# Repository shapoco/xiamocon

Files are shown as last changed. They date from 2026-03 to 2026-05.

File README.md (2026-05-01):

# [WIP] Xiamocon

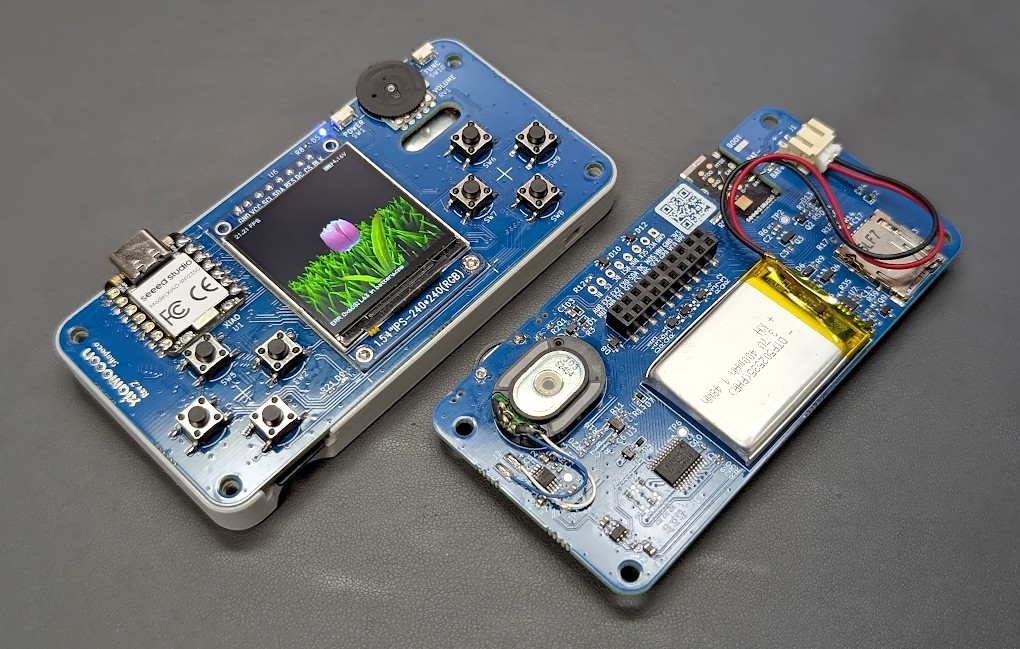
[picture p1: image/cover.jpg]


Game-console-style motherboard for XIAO RP2350/ESP32S3

> [!CAUTION]
> Everything is currently under development. Breaking changes may occur frequently without notice.

## Hardware Architecture

[Schematic](https://kicanvas.org/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)

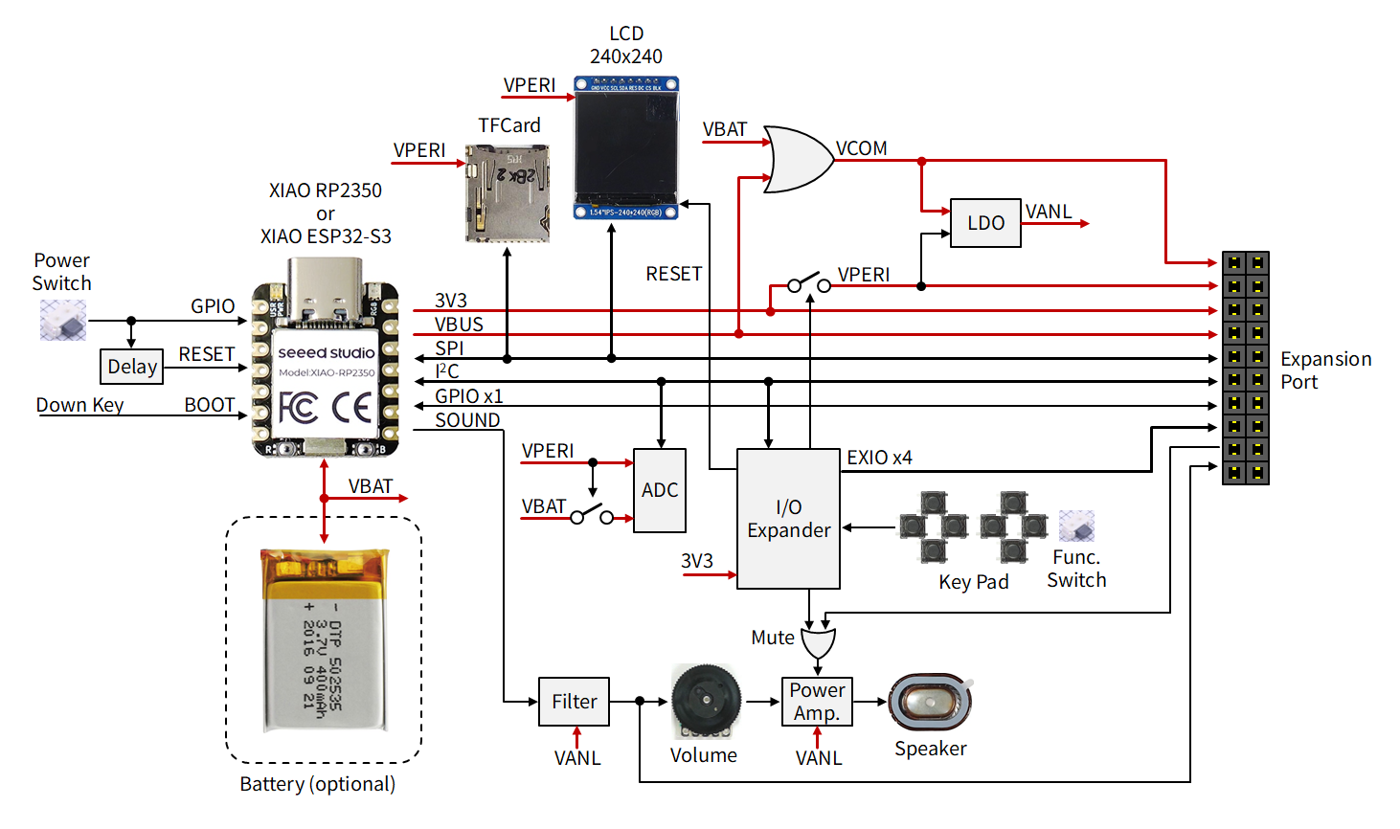
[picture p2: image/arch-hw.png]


## Development Environment Setup (Ubuntu24.04/macOS)

### 1. Install Build Tools

#### Install uv

See [Installing uv](https://docs.astral.sh/uv/getting-started/installation/).

#### Install other required packages

- Ubuntu24.04 (WSL2):

    ```sh
    sudo apt update
    sudo apt -y install curl git
    sudo apt -y install build-essential cmake gcc-arm-none-eabi
    ```

- macOS:

    First, install Command Line Developer Tools, [Homebrew](https://brew.sh/), and [CMake](https://cmake.org/download/), then run the following command:

    ```sh
    sudo "/Applications/CMake.app/Contents/bin/cmake-gui" --install
    brew install --cask gcc-arm-embedded
    ```

### 2. Install the Xiamocon SDK

```sh
curl -LsSf https://github.com/shapoco/xiamocon/raw/refs/heads/main/install.sh | bash
```

Python virtual enviroment, [Pico-SDK](https://github.com/raspberrypi/pico-sdk),
[Pico-Extras](https://github.com/raspberrypi/pico-extras), [PlatformIO](https://platformio.org/),
and this repository will be automatically installed in `${HOME}/.xmc/` directory.

### 3. Configure Environment Variables

To avoid setting the repository path every time, add the following line to your shell configuration file (e.g., `~/.bashrc`, `~/.zshrc`).

```sh
export XMC_REPO_PATH=${HOME}/.xmc/xiamocon
```

## Build and Run the Hello World Sample (Ubuntu24.04/macOS)

### For XIAO RP2350

1. Connect Xiamocon to your PC via USB and enter mass storage mode.
    1. Press and hold the Down button on Xiamocon.
    2. Press and hold the power button for 3 seconds to reset (it will be mounted as a mass storage device).
    3. Release the Down button.
2. Initialize the environment and move to the sample app directory.

    ```sh
    source ${HOME}/.xmc/setup.shrc
    cd ${XMC_REPO_PATH}
    cd cpp/example/hello_world
    ```

3. Build and flash the firmware.
    - On WSL2, you can specify the drive letter with the `-d` option to build and flash in one step (if the drive letter is E). You may be prompted for an administrator password.

        ```sh
        xmc run -p rp2350_pico_sdk -d E
        ```

    - On non-WSL2 environments, run `xmc build` instead of `xmc run`, then manually copy the generated UF2 file to the drive.

        ```sh
        xmc build -p rp2350_pico_sdk
        ```

### For XIAO ESP32S3

1. Connect Xiamocon to your PC via USB and check the serial port.
    - On WSL2, use [WSL USB Manager](https://github.com/nickbeth/wsl-usb-manager) or similar tools to attach Xiamocon's USB device to WSL2.
2. Initialize the environment and move to the sample app directory.

    ```sh
    source ${HOME}/.xmc/setup.shrc
    cd ${XMC_REPO_PATH}
    cd cpp/example/hello_world
    ```

3. Build and flash while specifying the serial port with the `-s` option.

    ```sh
    xmc run -p esp32s3_pio_arduino -s /dev/ttyACM0
    ```

    If you want to use PlatformIO's default serial port, you can omit the `-s` option.

>[!NOTE]
> - You can omit the `-p` option by setting the platform in the `XMC_DEFAULT_PLATFORM` environment variable.
> - You can omit the `-d` option by setting the drive letter in the `XMC_DEFAULT_DRIVE` environment variable.
> - You can omit the `-s` option by setting the serial port in the `XMC_DEFAULT_SERIAL` environment variable.

>[!NOTE]
> On ESP32S3, you can also build and flash using the PlatformIO extension in VSCode.

## Create a Project (Ubuntu24.04/macOS)

```sh
source ${HOME}/.xmc/setup.shrc
mkdir -p my_project
cd my_project
xmc init
cp -r ${XMC_REPO_PATH}/cpp/example/hello_world/src .
```

## Detailed Documentation

See the [Reference Manual](https://shapoco.github.io/xiamocon/ref/).

## Photos

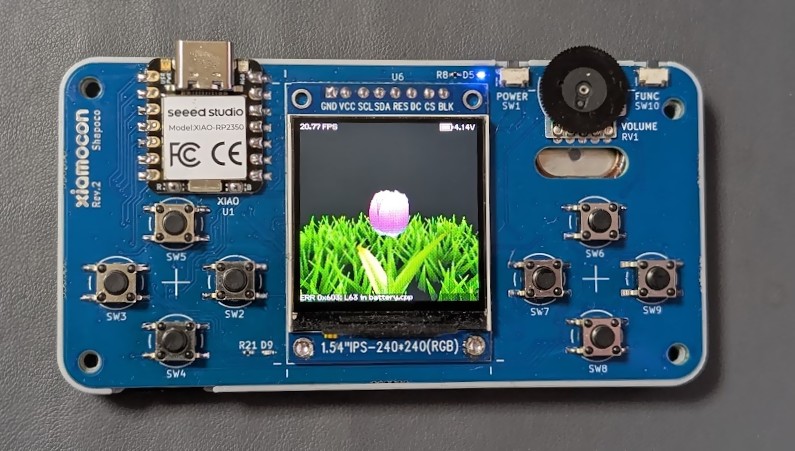
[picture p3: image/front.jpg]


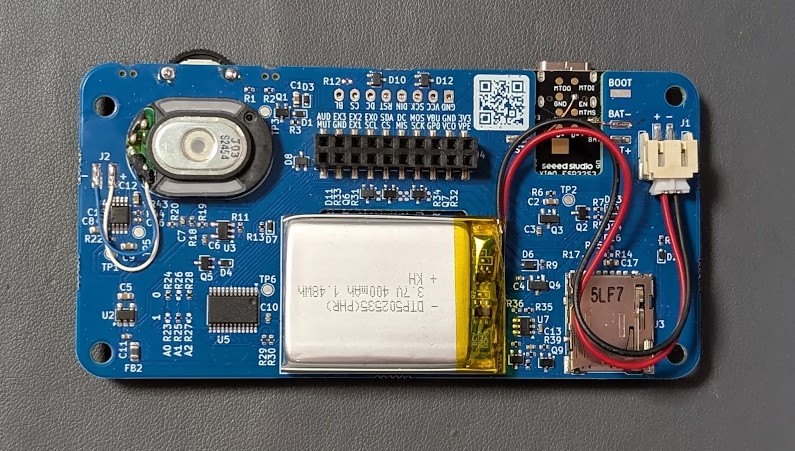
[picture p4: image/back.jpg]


## Videos

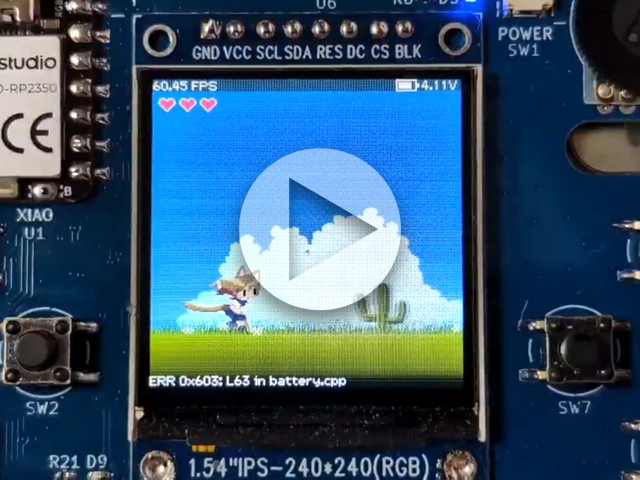
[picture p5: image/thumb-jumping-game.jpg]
(https://x.com/shapoco/status/2041168789505794345)


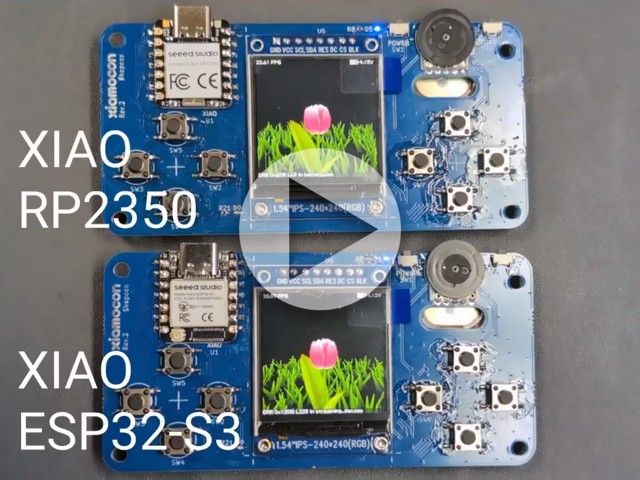
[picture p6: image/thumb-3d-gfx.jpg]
(https://x.com/shapoco/status/2038788120653824424)


## License

T.B.D.

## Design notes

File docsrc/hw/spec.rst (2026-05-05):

ハードウェア仕様
################################################################################

基本仕様
================================================================================

.. csv-table::
   :header: "項目", "値"

   "基板外形", "100x50mm"
   "MCU ボード", "Seeed Studio XIAO RP2350 または XIAO ESP32S3"
   "ディスプレイ", "1.54インチ 240x240px IPS 液晶 (ST7789)"
   "スピーカー", "ダイナミックスピーカー"
   "キーパッド", "タクトスイッチまたはゴム接点"
   "バッテリー(別売)", "DTP502535 (3.7V 400mAh)"
   "メモリーカード(別売)", "SPIモード専用"
   "拡張ポート", "20pin ピンソケット (I2C、SPI、GPIOx5、オーディオ)"
   "消費電力 (RP2350)", "約 400mW (100mA @ 4V)"
   "消費電力 (ESP32S3)", "約 500mW (120mA @ 4V)"
   "待機電流 (RP2350)", "約 80μA"
   "待機電流 (ESP32S3)", "約 20μA"

回路図
================================================================================

`xiamocon.kicad_sch <https://kicanvas.org/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>`__

電源
================================================================================

VBUS
--------------------------------------------------------------------------------

XIAO から供給される 5V の電源です。
USB ケーブルが接続されていれば XIAO の MCU の状態に関わらず常に供給されます。

VBAT
--------------------------------------------------------------------------------

バッテリーから供給される電源です。
バッテリーが接続されていれば XIAO の MCU の状態に関わらず常に供給されます。

3V3
--------------------------------------------------------------------------------

XIAO に内蔵された DC/DC コンバータによって生成される 3.3V の電源です。
USB ケーブルまたはバッテリーが接続されていれば、XIAO の MCU の状態に関わらず常に供給されます。

VPERI
--------------------------------------------------------------------------------

VPERI はペリフェラルに供給される 3.3V の電源です。
次の条件が両方満たされると供給されます。

- IO エキスパンダの PERI_EN_N が Low であること
- ディスプレイの CS と DC が少なくとも短時間 High であること

ディスプレイの CS と DC が長時間 Low またはハイインピーダンスになると、
PERI_EN_N が Low であっても VPERI の供給は停止します。
これにより XIAO のブートローダーが起動している間はペリフェラルの電源供給が停止します。

VCOM
--------------------------------------------------------------------------------

VCOM は VBUS (5V) と VBAT (バッテリー電圧) のうち高い方が供給されます。
VPERI とは無関係に供給されます。

VANL
--------------------------------------------------------------------------------

VANL はオーディオ回路の供給される 3.3V の電源で、VCOM からシリーズレギュレータによって生成されます。
シリーズレギュレータのイネーブルは VPERI と連動します。

ペリフェラル
================================================================================

電源スイッチ
--------------------------------------------------------------------------------

.. csv-table::
   :header: "信号名", "ピン (RP2350)", "ピン (ESP32S3)"

   "POWER", GPIO 27, GPIO 2

電源スイッチは遅延回路を介して XIAO のリセット端子にも接続されており、
長押しすることによってリセットすることができます。

ディスプレイ
--------------------------------------------------------------------------------

.. csv-table::
   :header: "信号名", "ピン (RP2350)", "ピン (ESP32S3)"

   "SCK", GPIO 2, GPIO 7
   "MOSI", GPIO 3, GPIO 9
   "DC", GPIO 28, GPIO 3
   "CS", GPIO 5, GPIO 4

リセット端子は IO エキスパンダの PORTA の 5 番に接続されています。

ディスプレイの電源は VPERI によって供給されます。

メモリーカード
--------------------------------------------------------------------------------

.. csv-table::
   :header: "信号名", "ピン (RP2350)", "ピン (ESP32S3)"

   "SCK", GPIO 2, GPIO 7
   "MOSI", GPIO 3, GPIO 9
   "MISO", GPIO 4, GPIO 8
   "CS", GPIO 0, GPIO 43

CS ピンを Low にドライブするとアクセスランプが点灯します。

メモリーカードの電源は VPERI によって供給されます。

オーディオ
--------------------------------------------------------------------------------

.. csv-table::
   :header: "信号名", "ピン (RP2350)", "ピン (ESP32S3)"

   "AUDIO_OUT", GPIO 1, GPIO 44

オーディオ出力はバッファ、ローパスフィルタ、ボリュームを介してパワーアンプに接続されます。
XIAO からの出力は PDM または PWM を想定しています。
パワーアンプのミュート端子は IO エキスパンダのポート A の 6 番に接続されています。

GPIO
--------------------------------------------------------------------------------

.. csv-table::
   :header: "信号名", "ピン (RP2350)", "ピン (ESP32S3)"

   "GPIO_0", GPIO 26, GPIO 1

GPIO 端子は拡張ポートに接続されています。

IO エキスパンダ
--------------------------------------------------------------------------------

デバイス: PCA9555

.. csv-table::
   :header: "型番", "デバイスアドレス"

   "PCA9555", "0x22"

.. csv-table::
   :header: "信号名", "ピン (RP2350)", "ピン (ESP32S3)"

   "SDA", GPIO 6, GPIO 5
   "SCL", GPIO 7, GPIO 6

.. csv-table::
   :header: "信号名", "接続先", "極性"

   "PORTA-0", "拡張ポート IOEX0", "ユーザー定義"
   "PORTA-1", "拡張ポート IOEX1", "ユーザー定義"
   "PORTA-2", "拡張ポート IOEX2", "ユーザー定義"
   "PORTA-3", "拡張ポート IOEX3", "ユーザー定義"
   "PORTA-4", "ペリフェラルイネーブル (PERI_EN_N)", "Low アクティブ"
   "PORTA-5", "ディスプレイリセット", "Low アクティブ"
   "PORTA-6", "オーディオミュート", "Low アクティブ"
   "PORTA-7", "ファンクションスイッチ", "Low アクティブ"
   "PORTB-0", "A ボタン", "Low アクティブ"
   "PORTB-1", "B ボタン", "Low アクティブ"
   "PORTB-2", "Y ボタン", "Low アクティブ"
   "PORTB-3", "X ボタン", "Low アクティブ"
   "PORTB-4", "↑ボタン", "Low アクティブ"
   "PORTB-5", "↓ボタン", "Low アクティブ"
   "PORTB-6", "←ボタン", "Low アクティブ"
   "PORTB-7", "→ボタン", "Low アクティブ"

バッテリー監視用 ADC
--------------------------------------------------------------------------------

.. csv-table::
   :header: "型番", "デバイスアドレス"

   "ADC101C027", "0x52"

.. csv-table::
   :header: "信号名", "ピン (RP2350)", "ピン (ESP32S3)"

   "SDA", GPIO 6, GPIO 5
   "SCL", GPIO 7, GPIO 6

ADC の電源は VPERI によって供給されます。

拡張ポート
=================================================================================

拡張ポートは基板の背面にあります。XIAO に近い側が 1 番ピンです。

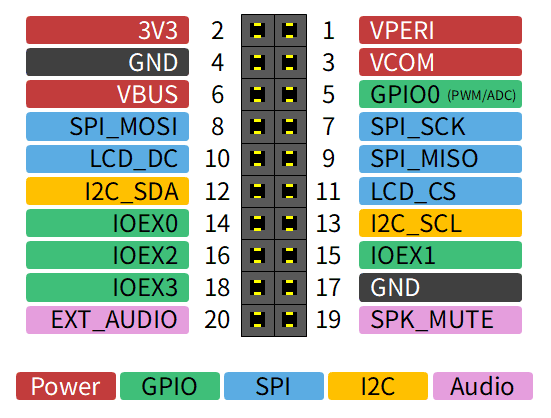
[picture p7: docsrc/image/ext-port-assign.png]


EXT_AUDIO はオーディオ回路から分岐した信号で、XIAO からのオーディオ出力を外部へ出力したり、
逆に外部からのオーディオ信号を入力して XIAO の出力とミックスしてスピーカーから出力できます。

SPK_MUTE はパワーアンプのミュート端子に接続されており、
High にドライブすることでXiamocon 本体のスピーカーをミュートできます。

GPIO0 と IOEX0-3 の用途はアプリ側で自由に定義できます。

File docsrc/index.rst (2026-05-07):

.. xiamocon documentation master file, created by
   sphinx-quickstart on Mon Apr 27 18:01:40 2026.
   You can adapt this file completely to your liking, but it should at least
   contain the root `toctree` directive.

Xiamocon Reference Manual
################################################################################

.. toctree::
   :maxdepth: 2
   :caption: Contents:

   hw/spec.rst
   hw/enclosure.rst
   sdk/app.rst
   sdk/gfx2d.rst
   sdk/gfx3d.rst
   sdk/audio.rst
   sdk/gpio.rst
   sdk/i2c.rst
   sdk/spi.rst
   sdk/pwm.rst
   sdk/adc.rst
   sdk/timer.rst
   sdk/heap.rst
   sdk/multicore.rst
   sdk/flash.rst
   sdk/semaphore.rst
   sdk/spinlock.rst
   troubleshoot.rst

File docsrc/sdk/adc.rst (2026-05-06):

ADC API
################################################################################

概要
================================================================================

ADC API は、単一ピンの ADC 入力を初期化し、RAW 値または電圧値として読み取るための低レベル API です。

`xmc::adc::createAdcDriver()` で生成して使用します。

設定
================================================================================

xmc::adc::AdcConfig
--------------------------------------------------------------------------------

.. code-block:: cpp

	struct xmc::adc::AdcConfig {};

ADC 初期化時に使用する設定構造体です。
現行定義ではメンバーはありませんが、将来の設定拡張点として用意されています。

xmc::adc::getDefaultAdcConfig
--------------------------------------------------------------------------------

.. code-block:: cpp

	xmc::adc::AdcConfig xmc::adc::getDefaultAdcConfig();

推奨デフォルト値で初期化された `AdcConfig` を返します。
`AdcDriverClass::init()` に渡す設定値を取得するために使用します。

AdcDriver
================================================================================

AdcDriver は std::shared_ptr<AdcDriverClass> のエイリアスです。

xmc::adc::createAdcDriver
--------------------------------------------------------------------------------

.. code-block:: cpp

	xmc::adc::AdcDriver xmc::adc::createAdcDriver(int pin = XMC_PIN_GPIO_0);

`AdcDriver` を生成して返します。
通常はこの関数でドライバを作成し、`init()` 後に `readRaw()` / `readVoltage()` を使用します。

init
--------------------------------------------------------------------------------

.. code-block:: cpp

	XmcStatus xmc::adc::AdcDriverClass::init(const xmc::adc::AdcConfig &cfg);

ADC ドライバを初期化します。
`cfg` には初期化設定を指定します。戻り値は `XmcStatus` で、成功時は `XMC_OK` です。

deinit
--------------------------------------------------------------------------------

.. code-block:: cpp

	void xmc::adc::AdcDriverClass::deinit();

ADC ドライバを終了します。
以後 ADC を使用しない場合に呼び出します。

getMaxValue
--------------------------------------------------------------------------------

.. code-block:: cpp

	void xmc::adc::AdcDriverClass::getMaxValue(uint16_t *raw = nullptr, float *voltage = nullptr);

ADC の最大 RAW 値と最大電圧を取得します。

`raw` が `nullptr` でない場合は最大 RAW 値を書き込み、`voltage` が `nullptr` でない場合は基準となる最大電圧 [V] を書き込みます。

readRaw
--------------------------------------------------------------------------------

.. code-block:: cpp

	XmcStatus xmc::adc::AdcDriverClass::readRaw(uint16_t *value);

ADC を 1 回サンプリングし、RAW 値を取得します。
`value` に読み取り結果を書き込みます。戻り値は `XmcStatus` です。

readVoltage
--------------------------------------------------------------------------------

.. code-block:: cpp

	XmcStatus xmc::adc::AdcDriverClass::readVoltage(float *value);

ADC を 1 回サンプリングし、電圧値 [V] として取得します。
`value` に変換結果を書き込み、戻り値は `XmcStatus` です。

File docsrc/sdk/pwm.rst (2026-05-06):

PWM API
################################################################################

概要
================================================================================

PWM API は、単一ピンのハードウェア PWM 出力を制御するための低レベル API です。

`xmc::pwm::createPwmDriver()` で生成して使用します。

設定
================================================================================

xmc::pwm::PwmConfig
--------------------------------------------------------------------------------

.. code-block:: cpp

	struct xmc::pwm::PwmConfig {
	  uint32_t freqHz;
	  uint32_t period;
	};

PWM 初期化時に使用する設定構造体です。

`freqHz` には PWM の周波数を Hz 単位で指定します。
`period` にはデューティサイクルの最大値（分解能）を指定します。

xmc::pwm::getDefaultPwmConfig
--------------------------------------------------------------------------------

.. code-block:: cpp

	xmc::pwm::PwmConfig xmc::pwm::getDefaultPwmConfig();

推奨デフォルト値で初期化された `PwmConfig` を返します。
`PwmDriverClass::start()` に渡す設定値を取得するために使用します。

PwmDriver
================================================================================

PwmDriver は std::shared_ptr<PwmDriverClass> のエイリアスです。

xmc::pwm::createPwmDriver
--------------------------------------------------------------------------------

.. code-block:: cpp

	xmc::pwm::PwmDriver xmc::pwm::createPwmDriver(int pin = XMC_PIN_GPIO_0);

`PwmDriver` を生成して返します。
通常はこの関数でドライバを作成し、`start()` 後に `write()` を使用します。

start
--------------------------------------------------------------------------------

.. code-block:: cpp

	XmcStatus xmc::pwm::PwmDriverClass::start(const xmc::pwm::PwmConfig &cfg, float *actualFreqHz = nullptr);

PWM 信号の生成を開始します。

`cfg` には初期化設定を指定します。
`actualFreqHz` が `nullptr` でない場合は、実際に設定された周波数 [Hz] を書き込みます。

戻り値は `XmcStatus` で、成功時は `XMC_OK` です。

stop
--------------------------------------------------------------------------------

.. code-block:: cpp

	XmcStatus xmc::pwm::PwmDriverClass::stop();

PWM 信号の生成を停止します。
戻り値は `XmcStatus` で、成功時は `XMC_OK` です。

write
--------------------------------------------------------------------------------

.. code-block:: cpp

	XmcStatus xmc::pwm::PwmDriverClass::write(uint32_t cycle);

PWM のデューティサイクルを設定します。

`cycle` には 0 から `PwmConfig::period` の範囲でデューティサイクル値を指定します。
戻り値は `XmcStatus` で、成功時は `XMC_OK` です。

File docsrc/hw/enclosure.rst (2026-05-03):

エンクロージャ
################################################################################

簡易版
================================================================================

タクトスイッチを用いる場合の簡易版エンクロージャです。
フロントパネルはありません。

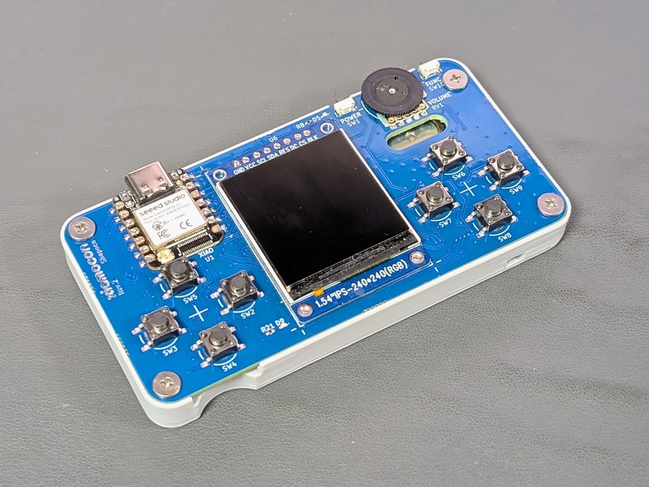
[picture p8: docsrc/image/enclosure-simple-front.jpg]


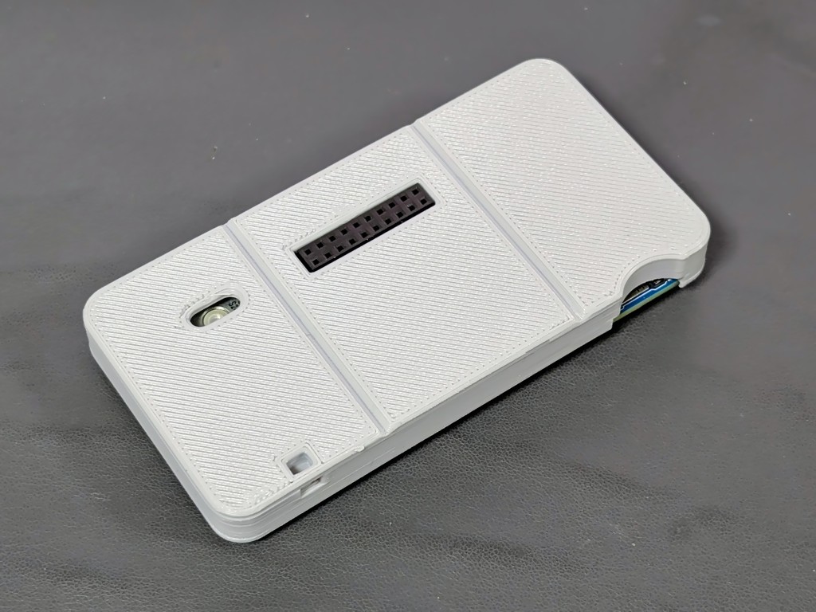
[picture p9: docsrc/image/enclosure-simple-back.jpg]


3D データ
--------------------------------------------------------------------------------

- ボディ:

    - `simple.step <https://github.com/shapoco/xiamocon/blob/main/enclosure/simple/simple.step>`__
    - `simple.stl <https://github.com/shapoco/xiamocon/blob/main/enclosure/simple/simple.stl>`__

ネジ止めには 3x8mm の低頭タッピングネジを 4 つ使用します。

バッテリーを内蔵する場合は、中で揺れないようにクッションとしてスポンジなどを入れてください。

フル版
================================================================================

ゲーム機のコントローラの修理用ゴムパッドを使ったエンクロージャです。

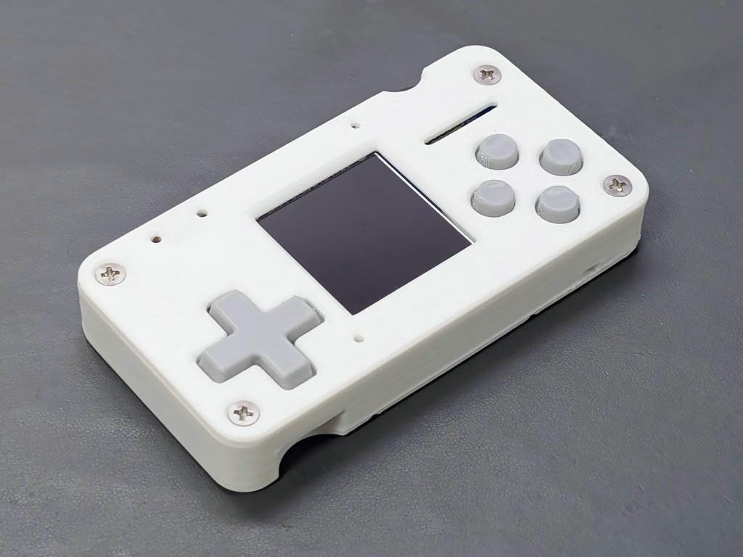
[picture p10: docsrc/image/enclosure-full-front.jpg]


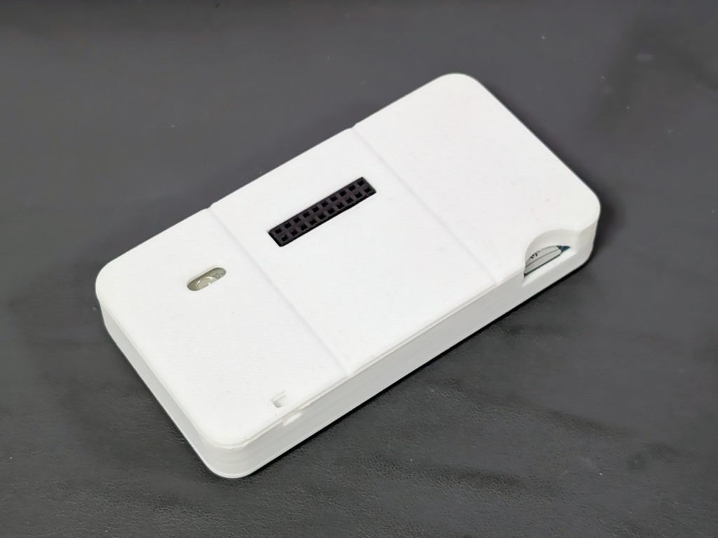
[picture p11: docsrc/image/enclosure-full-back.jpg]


3D データ
--------------------------------------------------------------------------------

- ボディ:

    - `full_body.step <https://github.com/shapoco/xiamocon/blob/main/enclosure/full/full_body.step>`__
    - `full_body.stl <https://github.com/shapoco/xiamocon/blob/main/enclosure/full/full_body.stl>`__

- キー:

    - `full_keys.step <https://github.com/shapoco/xiamocon/blob/main/enclosure/full/full_keys.step>`__
    - `full_keys.stl <https://github.com/shapoco/xiamocon/blob/main/enclosure/full/full_keys.stl>`__

組み立て手順
--------------------------------------------------------------------------------

以下のものを用意します。

- Xiamocon 本体
- PS4 / PS5 / スーパーファミコンのコントローラ用ゴムパッド (十字キー側のもの) x2
- 3x12mm 皿頭タッピングネジ x4
- 3D プリント部品
- バッテリー用クッション (必要に応じて)

ゴムパッドは十字キー側のものを 2 つ使用しますので 2 セット調達してください。

キーのモデルは積層痕がボディに引っかからないよう、垂直に立てた状態のモデルデータになっています。
サポートを付けてプリントしてください。

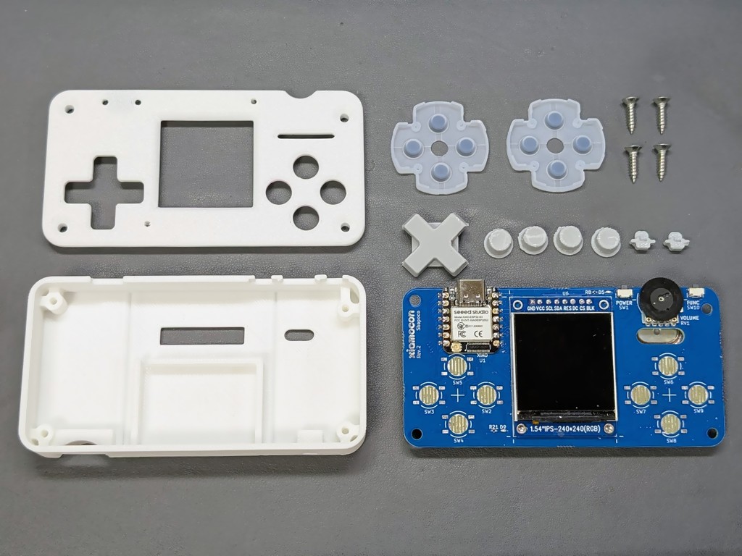
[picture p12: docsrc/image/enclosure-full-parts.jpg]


ゲームコントローラの修理用ゴムパッドを、ケース内に収まるようハサミ等でカットします。

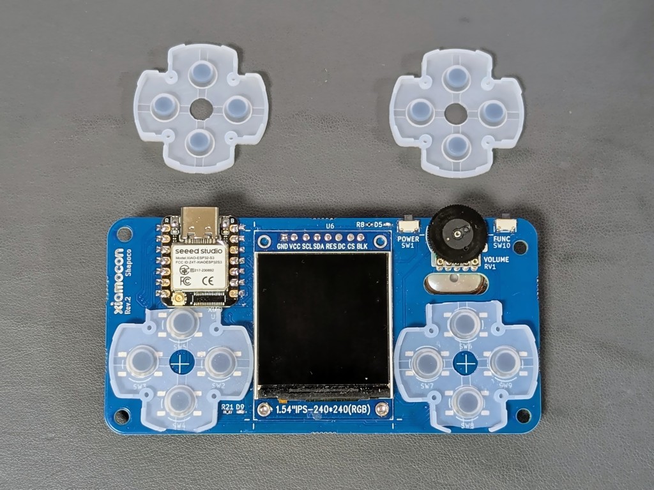
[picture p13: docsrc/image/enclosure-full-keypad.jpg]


バッテリーを内蔵する場合は、中で揺れないようにクッションとしてスポンジなどを入れてください。

バックパネルに Xiamocon 本体を載せ、加工したゴムパッドを配置し、キーを載せます。
電源ボタンとファンクションボタンにもキーをかぶせ、フロントパネルを載せて四隅をネジ止めします。

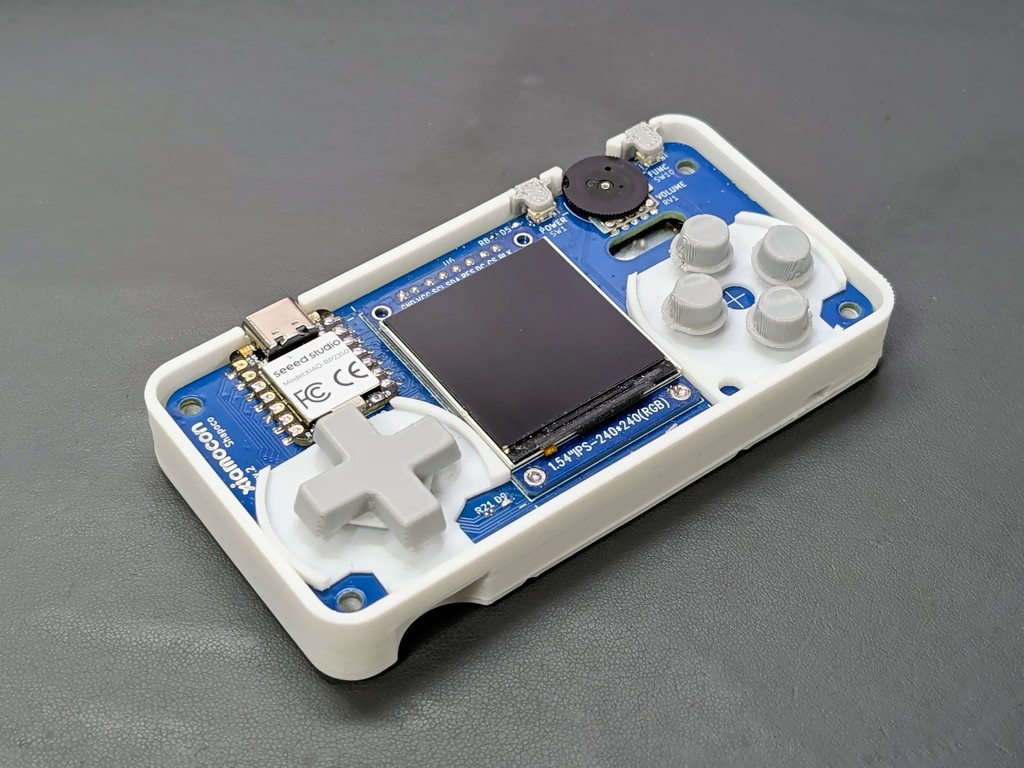
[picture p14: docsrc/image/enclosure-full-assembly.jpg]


ネジを強く締めすぎてネジ穴を舐めてしまわないようにご注意ください。

接触が悪くなったときは、接点を鉛筆やシャープペンシルのペンでこすると復活します。

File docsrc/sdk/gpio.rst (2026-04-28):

GPIO API
################################################################################

概要
================================================================================

GPIO API は、汎用デジタル入出力ピンの方向設定、出力、入力、およびプルアップ制御を行うための低レベル API です。

ピン番号には `xmc/pins.hpp` で定義される定数 (例: `XMC_PIN_GPIO_0`) を指定して使用します。

グローバル関数
================================================================================

xmc::gpio::setDir
--------------------------------------------------------------------------------

.. code-block:: cpp

	void xmc::gpio::setDir(int pin, bool output);

GPIO の方向を設定します。

`pin` には対象ピン番号を指定します。
`output` が `true` の場合は出力、`false` の場合は入力として設定されます。

xmc::gpio::write
--------------------------------------------------------------------------------

.. code-block:: cpp

	void xmc::gpio::write(int pin, bool value);

GPIO 出力値を設定します。

`value` が `true` なら High、`false` なら Low を出力します。
通常は事前に `setDir(pin, true)` で出力モードに設定してから使用します。

xmc::gpio::read
--------------------------------------------------------------------------------

.. code-block:: cpp

	bool xmc::gpio::read(int pin);

GPIO 入力値を読み取ります。

戻り値は、High レベルなら `true`、Low レベルなら `false` です。

xmc::gpio::setPullup
--------------------------------------------------------------------------------

.. code-block:: cpp

	void xmc::gpio::setPullup(int pin, bool enable);

GPIO の内部プルアップ抵抗を設定します。

`enable` が `true` の場合は有効、`false` の場合は無効です。
入力ピンでの利用を想定しています。

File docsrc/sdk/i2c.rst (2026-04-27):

I2C API
################################################################################

概要
================================================================================

I2C API は、I2C デバイスへの同期アクセスを行うための低レベル API です。
複数タスクから安全に利用するため、アクセス時は `lock()` / `unlock()` でトランザクションを保護します。

初期化
================================================================================

xmc::i2c::getPreferredFrequency
--------------------------------------------------------------------------------

.. code-block:: cpp

	uint32_t xmc::i2c::getPreferredFrequency(Chipset device);

デバイス種別に応じた推奨 I2C クロック周波数 [Hz] を返します。

`device` には接続先デバイス種別を指定します。
戻り値は、そのデバイスで安全に使用できることを想定した推奨クロック周波数です。

xmc::i2c::init
--------------------------------------------------------------------------------

.. code-block:: cpp

	XmcStatus xmc::i2c::init();

I2C ペリフェラルを初期化します。

I2C API を使う前に一度だけ呼び出します。
戻り値は `XmcStatus` で、成功時は `XMC_OK` です。

xmc::i2c::deinit
--------------------------------------------------------------------------------

.. code-block:: cpp

	void xmc::i2c::deinit();

I2C ペリフェラルを終了します。

以後 I2C を使用しない場合に呼び出します。戻り値はありません。

トランザクション制御
================================================================================

xmc::i2c::tryLock
--------------------------------------------------------------------------------

.. code-block:: cpp

	bool xmc::i2c::tryLock();

非ブロッキングで I2C ロック取得を試みます。

ロック取得に成功した場合は `true`、他の処理が使用中で取得できなかった場合は `false` を返します。

xmc::i2c::lock
--------------------------------------------------------------------------------

.. code-block:: cpp

	XmcStatus xmc::i2c::lock();

ロックが取得できるまで待機してから I2C トランザクションを開始します。

戻り値は `XmcStatus` です。通常は `XMC_OK` が返ります。

xmc::i2c::unlock
--------------------------------------------------------------------------------

.. code-block:: cpp

	XmcStatus xmc::i2c::unlock();

I2C トランザクションを終了します。

`lock()` または `tryLock()` で開始したトランザクションの終端として呼び出します。
戻り値は `XmcStatus` です。

通信設定とバス復旧
================================================================================

xmc::i2c::setBaudrate
--------------------------------------------------------------------------------

.. code-block:: cpp

	XmcStatus xmc::i2c::setBaudrate(uint32_t baudrate);

I2C 通信速度 [Hz] を設定します。

`baudrate` には希望するクロック周波数を指定します。
戻り値は `XmcStatus` で、プラットフォームが設定に失敗した場合はエラーコードを返します。

xmc::i2c::resetBus
--------------------------------------------------------------------------------

.. code-block:: cpp

	XmcStatus xmc::i2c::resetBus();

SCL トグルによりスタックしたバスを復旧します。

スレーブが SDA を保持したままになった場合など、異常状態からの回復に使用します。
戻り値は `XmcStatus` です。

データ転送
================================================================================

xmc::i2c::writeBlocking
--------------------------------------------------------------------------------

.. code-block:: cpp

	XmcStatus xmc::i2c::writeBlocking(uint8_t devAddr, const uint8_t *data, uint32_t size, bool nostop);

I2C デバイスへデータを書き込みます。
`devAddr` は 7bit アドレスです。

`data` は送信するバッファ先頭アドレス、`size` は送信バイト数です。
`nostop` を `true` にすると STOP 条件を出さずに終了するため、続けて repeated start を伴う操作を行えます。

戻り値は `XmcStatus` です。

xmc::i2c::readBlocking
--------------------------------------------------------------------------------

.. code-block:: cpp

	XmcStatus xmc::i2c::readBlocking(uint8_t devAddr, uint8_t *data, uint32_t size, bool nostop);

I2C デバイスからデータを読み出します。

`nostop` を `true` にすると STOP 条件を出さないため、
レジスタアドレス書き込み後の連続読み出しなどに利用できます。

`data` は受信データの格納先、`size` は受信バイト数です。
戻り値は `XmcStatus` です。

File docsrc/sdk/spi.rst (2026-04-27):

SPI API
################################################################################

概要
================================================================================

SPI API は、同期転送と DMA 転送の両方を提供します。
複数タスクから利用する場合は `lock()` / `unlock()` でトランザクションを保護します。

xmc::spi::getPreferredFrequency
================================================================================

.. code-block:: cpp

	uint32_t xmc::spi::getPreferredFrequency(Chipset device);

デバイス種別に応じた推奨 SPI クロック [Hz] を返します。

`device` には接続先デバイス種別を指定します。
戻り値は、そのデバイスでの使用を想定した推奨 SPI クロックです。

初期化
================================================================================

xmc::spi::init
--------------------------------------------------------------------------------

.. code-block:: cpp

	XmcStatus xmc::spi::init();

SPI ペリフェラルを初期化します。

SPI API を利用する前に呼び出します。
戻り値は `XmcStatus` で、成功時は `XMC_OK` です。

xmc::spi::deinit
--------------------------------------------------------------------------------

.. code-block:: cpp

	void xmc::spi::deinit();

SPI ペリフェラルを終了します。

以後 SPI を使用しない場合に呼び出します。戻り値はありません。

トランザクション制御
================================================================================

xmc::spi::tryLock
--------------------------------------------------------------------------------

.. code-block:: cpp

	bool xmc::spi::tryLock();

非ブロッキングで SPI ロック取得を試みます。

取得成功時は `true`、取得失敗時は `false` を返します。

xmc::spi::lock
--------------------------------------------------------------------------------

.. code-block:: cpp

	XmcStatus xmc::spi::lock();

ロックが取得できるまで待機してから SPI トランザクションを開始します。

戻り値は `XmcStatus` です。通常は `XMC_OK` が返ります。

xmc::spi::unlock
--------------------------------------------------------------------------------

.. code-block:: cpp

	XmcStatus xmc::spi::unlock();

SPI トランザクションを終了します。

戻り値は `XmcStatus` です。

通信設定
================================================================================

xmc::spi::setBaudrate
--------------------------------------------------------------------------------

.. code-block:: cpp

	XmcStatus xmc::spi::setBaudrate(uint32_t baudrate);

SPI 通信速度 [Hz] を設定します。

`baudrate` には希望するクロック周波数を指定します。
戻り値は `XmcStatus` です。

同期転送
================================================================================

xmc::spi::writeBlocking
--------------------------------------------------------------------------------

.. code-block:: cpp

	XmcStatus xmc::spi::writeBlocking(const uint8_t *data, uint32_t size);

SPI へブロッキング書き込みを行います。

`data` は送信バッファ先頭、`size` は送信バイト数です。
戻り値は `XmcStatus` です。

xmc::spi::readBlocking
--------------------------------------------------------------------------------

.. code-block:: cpp

	XmcStatus xmc::spi::readBlocking(uint8_t repeated_byte, uint8_t *data, uint32_t size);

読み出し中に `repeated_byte` を送信しながら、`size` バイト受信します。

`data` は受信バッファ先頭、`size` は受信バイト数です。
戻り値は `XmcStatus` です。

DMA 転送
================================================================================

xmc::spi::dmaWriteStart
--------------------------------------------------------------------------------

.. code-block:: cpp

	XmcStatus xmc::spi::dmaWriteStart(const xmc::dma::Config *cfg, int csPin);

DMA 書き込みを開始します。関数は転送完了を待たずに返ります。

`cfg` の主なメンバー:

- `ptr`: 転送元バッファ
- `elementSize`: 要素サイズ [byte]
- `length`: 要素数

`csPin` に 0 以上を指定すると、転送中のみ CS を自動制御します。

戻り値は `XmcStatus` です。転送開始に成功した時点で返るため、完了確認には `dmaComplete()` または `dmaIsBusy()` を使用します。

xmc::spi::dmaComplete
--------------------------------------------------------------------------------

.. code-block:: cpp

	XmcStatus xmc::spi::dmaComplete();

進行中 DMA 転送の完了を待機します。

戻り値は `XmcStatus` です。DMA 転送と必要な CS 解放処理が完了した時点で返ります。

xmc::spi::dmaIsBusy
--------------------------------------------------------------------------------

.. code-block:: cpp

	bool xmc::spi::dmaIsBusy();

DMA 転送中かどうかを返します。

転送中は `true`、アイドル状態では `false` を返します。

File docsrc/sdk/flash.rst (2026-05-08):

Flash API
################################################################################

概要
================================================================================

Flash API は、内蔵フラッシュメモリへのデータ書き込みおよびメモリマップアクセスを提供する低レベル API です。

`xmc::flash::init()` で初期化した後、`write()` でデータを書き込み、`mmap()` / `munmap()` でメモリマップ読み出しを行います。

情報取得
================================================================================

xmc::flash::getSectorSize
--------------------------------------------------------------------------------

.. code-block:: cpp

	size_t xmc::flash::getSectorSize();

フラッシュメモリのセクターサイズをバイト単位で返します。
書き込み・消去の最小単位として使用します。

xmc::flash::getRange
--------------------------------------------------------------------------------

.. code-block:: cpp

	void xmc::flash::getRange(size_t *base, size_t *size);

フラッシュメモリの読み可能な領域のベースオフセットとサイズを取得します。

`base` が `nullptr` でない場合はベースオフセット [バイト] を書き込み、
`size` が `nullptr` でない場合は領域全体のサイズ [バイト] を書き込みます。

RP2350 版ではプログラムデータを含む Flash 領域全体の空間を返します。
書き込みを行う場合、通常は使用されていない末尾から使用します。

ESP32S3 版では SPIFFS パーティションの領域を返します。
書き込みを行うと、既存のファイルシステムは破壊されます。

書き込み・マップ
================================================================================

xmc::flash::erase
--------------------------------------------------------------------------------

.. code-block:: cpp

	XmcStatus xmc::flash::erase(uint32_t offset, size_t size);

フラッシュメモリの指定領域を消去します。

`offset` には消去開始オフセット [バイト] を指定します。
`size` には消去するバイト数を指定します。実際にはセクターサイズに切り上げて消去されます。

戻り値は `XmcStatus` で、成功時は `XMC_OK` です。

xmc::flash::write
--------------------------------------------------------------------------------

.. code-block:: cpp

	XmcStatus xmc::flash::write(uint32_t offset, const void *data, size_t size);

フラッシュメモリにデータを書き込みます。

`offset` には書き込み先のオフセット [バイト] を指定します。
`data` には書き込むデータのポインタを指定します。
`size` には書き込むバイト数を指定します。

書き込み前に対象領域を消去する場合は `erase()` を別途呼び出してください。

戻り値は `XmcStatus` で、成功時は `XMC_OK` です。

xmc::flash::mmap
--------------------------------------------------------------------------------

.. code-block:: cpp

	XmcStatus xmc::flash::mmap(uint32_t offset, size_t size, void **handle, const uint8_t **outPtr);

フラッシュメモリの指定領域をメモリマップします。

`offset` にはマップ開始オフセット [バイト] を指定します。
`size` にはマップするサイズ [バイト] を指定します。
`handle` にはマップ解除時に `munmap()` へ渡すハンドルが書き込まれます。
`outPtr` にはマップ後のアドレスが書き込まれます。

戻り値は `XmcStatus` で、成功時は `XMC_OK` です。

xmc::flash::munmap
--------------------------------------------------------------------------------

.. code-block:: cpp

	void xmc::flash::munmap(void *handle);

`mmap()` でマップした領域を解除します。
`handle` には `mmap()` で取得したハンドルを指定します。

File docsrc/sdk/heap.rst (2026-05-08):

Heap API
################################################################################

概要
================================================================================

Heap API は、プラットフォーム依存の RAM 特性を考慮した動的メモリ確保を行うための API です。

この API は C リンケージで提供されるため、C/C++ のどちらからでも利用できます。

型
================================================================================

XmcHeapCap
--------------------------------------------------------------------------------

RAM の特性を指定するビットフラグ列挙型です。

.. csv-table:: XmcHeapCap の値
	 :header: "値", "説明"

	 "XMC_HEAP_CAP_NONE", "特別な特性を要求しない。"
	 "XMC_HEAP_CAP_DMA", "DMA 可能な RAM を要求する。"
	 "XMC_HEAP_CAP_SPIRAM", "SPIRAM を要求する。"

複数の特性を要求する場合は OR (`|`) で組み合わせます。
割り当て可否と選択されるメモリ領域はプラットフォーム実装に依存します。

グローバル関数
================================================================================

xmcHasSpiRam
--------------------------------------------------------------------------------

.. code-block:: cpp

	bool xmcHasSpiRam();

システムに SPIRAM (PSRAM) が搭載されているかどうかを返します。

SPIRAM が利用可能であれば `true` を、利用不可であれば `false` を返します。

xmcMalloc
--------------------------------------------------------------------------------

.. code-block:: cpp

	void *xmcMalloc(size_t size, XmcHeapCap caps);

指定サイズのメモリ領域を確保します。

`size` には確保バイト数、`caps` には要求する RAM 特性を指定します。
確保に成功した場合は確保領域へのポインタを返し、失敗した場合は `NULL` を返します。

ESP32S3 版では、第二引数に XMC_HEAP_CAP_SPIRAM を指定すると PSRAM に確保されます。
これは SRAM の不足を回避するのに有効です。

RP2350 版では第二引数は無視され、常に SRAM に確保されます。

xmcFree
--------------------------------------------------------------------------------

.. code-block:: cpp

	void xmcFree(void *ptr);

`xmcMalloc()` で確保したメモリ領域を解放します。

`ptr` には解放対象のポインタを指定します。

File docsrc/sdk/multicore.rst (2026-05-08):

マルチコア API
################################################################################

概要
================================================================================

マルチコア API は、セカンダリコア (core1) 上でタスク関数を反復実行するための API を提供します。

core1 で実行する関数は、戻り値で継続可否を制御します。

型
================================================================================

xmc::Core1TaskFunc
--------------------------------------------------------------------------------

.. code-block:: cpp

	using xmc::Core1TaskFunc = bool (*)();

core1 で実行するタスク関数の型です。

関数が `true` を返すと次の反復へ進み、`false` を返すと core1 のタスクループを終了します。

グローバル関数
================================================================================

xmc::startCore1
--------------------------------------------------------------------------------

.. code-block:: cpp

	XmcStatus xmc::startCore1(xmc::Core1TaskFunc task);

指定したタスク関数を core1 で起動します。

`task` は core1 上で繰り返し呼び出されます。
すでに core1 が起動済みの場合は失敗し、エラーコードが返されます。

戻り値は `XmcStatus` で、成功時は `XMC_OK` です。

xmc::stopCore1
--------------------------------------------------------------------------------

.. code-block:: cpp

	XmcStatus xmc::stopCore1(uint32_t timeoutMs = 1000);

動作中の core1 を停止します。

`timeoutMs` には停止完了を待つ最大時間 [ms] を指定します。
停止要求後、タスクが終了しない場合はプラットフォーム実装に応じて core1 が強制的にリセットされます。

戻り値は `XmcStatus` です。成功時は `XMC_OK`、停止失敗時はエラーコードが返されます。

xmc::isCore1Running
--------------------------------------------------------------------------------

.. code-block:: cpp

	bool xmc::isCore1Running();

core1 が現在タスクを実行中かどうかを返します。

core1 が起動中であれば `true` を、停止中であれば `false` を返します。

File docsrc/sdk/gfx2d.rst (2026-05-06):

2D グラフィックス API
################################################################################

概要
================================================================================

2D 描画は主に次の 3 つの要素で構成されます。

- Sprite: 画像バッファ
- Graphics2D: Sprite への描画操作
- FrameBuffer: 画面転送を含む描画フレーム管理

ピクセルフォーマット
================================================================================

xmc::PixelFormat
--------------------------------------------------------------------------------

.. csv-table:: xmc::PixelFormat の値
	 :header: "値", "説明"

	 "xmc::PixelFormat::GRAY1", "1bit グレイスケール"
	 "xmc::PixelFormat::RGB444", "12bit RGB"
	 "xmc::PixelFormat::ARGB4444", "16bit ARGB"
	 "xmc::PixelFormat::RGB565", "16bit RGB"

xmc::Colors
--------------------------------------------------------------------------------

代表的な色定数です。

.. csv-table:: xmc::Colors の主な値
	 :header: "値", "説明"

	 "xmc::Colors::BLACK", "黒"
	 "xmc::Colors::WHITE", "白"
	 "xmc::Colors::RED", "赤"
	 "xmc::Colors::GREEN", "緑"
	 "xmc::Colors::BLUE", "青"
	 "xmc::Colors::YELLOW", "黄"
	 "xmc::Colors::CYAN", "シアン"
	 "xmc::Colors::MAGENTA", "マゼンタ"

Sprite
================================================================================

xmc::createSprite565 / 444 / 4444 / Gray1
--------------------------------------------------------------------------------

.. code-block:: cpp

	xmc::Sprite xmc::createSprite565(int width, int height, XmcHeapCap caps = XMC_HEAP_CAP_DMA);
	xmc::Sprite xmc::createSprite565(int width, int height, void *data, uint32_t stride = 0, bool autoFree = false);

	xmc::Sprite xmc::createSprite444(int width, int height, XmcHeapCap caps = XMC_HEAP_CAP_DMA);
	xmc::Sprite xmc::createSprite444(int width, int height, void *data, uint32_t stride = 0, bool autoFree = false);

	xmc::Sprite xmc::createSprite4444(int width, int height, XmcHeapCap caps = XMC_HEAP_CAP_DMA);
	xmc::Sprite xmc::createSprite4444(int width, int height, void *data, uint32_t stride = 0, bool autoFree = false);

	xmc::Sprite xmc::createSpriteGray1(int width, int height, XmcHeapCap caps = XMC_HEAP_CAP_DMA);
	xmc::Sprite xmc::createSpriteGray1(int width, int height, void *data, uint32_t stride = 0, bool autoFree = false);

Sprite を生成します。スプライトのピクセルフォーマットに応じた関数を使用します。

width と height にはスプライトのサイズをピクセル単位で指定します。

RAM 上にスプライトを作成する場合は、`caps` に RAM の種類を指定します。
スプライトを DMA 転送に使用する場合は `XMC_HEAP_CAP_DMA` を指定しなければなりません。

RAM 上に既に確保されたバッファや Flash ROM 上のリソースをスプライトとして使用する場合は、`data` 引数にバッファの先頭アドレスを指定します。
この場合、`stride` 引数に 1 ラインあたりのバイト数を指定します。0 を指定した場合は、幅に応じた値が自動計算されます。
`autoFree` を `true` にすると、スプライトオブジェクトの寿命が尽きたときに `data` で指定されたバッファを自動的に解放します。

xmc::SpriteClass
--------------------------------------------------------------------------------

Sprite の実体クラスです。`xmc::Sprite` は `std::shared_ptr<xmc::SpriteClass>` の別名です。

.. csv-table:: xmc::SpriteClass の主なメンバー
	 :header: "型", "メンバー", "説明"

	 "xmc::PixelFormat", "format", "ピクセルフォーマット"
	 "int", "width", "画像幅"
	 "int", "height", "画像高さ"
	 "uint32_t", "stride", "1 ラインあたりのバイト数"
	 "void *", "data", "ピクセルデータ先頭ポインタ"

xmc::SpriteClass::linePtr
--------------------------------------------------------------------------------

.. code-block:: cpp

	void *xmc::SpriteClass::linePtr(int y) const;

指定行の先頭ポインタを取得します。範囲外の `y` を指定した場合は `nullptr` を返します。

Graphics2D
================================================================================

コンストラクタ
--------------------------------------------------------------------------------

.. code-block:: cpp

	xmc::Graphics2D xmc::createGraphics2D();
	xmc::Graphics2D xmc::createGraphics2D(xmc::Sprite target);

`Graphics2D` インスタンスを生成します。
`target` 指定版は描画先 Sprite を初期設定した状態で生成します。

引数を指定しなかった場合、スプライトではなくディスプレイへ直接描画されます。

戻り値として `xmc::Graphics2D` オブジェクトを返します。

setTarget / getTarget
--------------------------------------------------------------------------------

.. code-block:: cpp

	void xmc::Graphics2DClass::setTarget(xmc::Sprite &s);
	xmc::Sprite xmc::Graphics2DClass::getTarget() const;

描画先 Sprite を設定・取得します。

`setTarget()` の引数 `s` には、新しい描画先として使用する Sprite を指定します。
`getTarget()` は現在設定されている描画先 Sprite を返します。

setClipRect / clearClipRect
--------------------------------------------------------------------------------

.. code-block:: cpp

	void xmc::Graphics2DClass::setClipRect(const xmc::Rect &rect);
	void xmc::Graphics2DClass::setClipRect(int x, int y, int w, int h);
	void xmc::Graphics2DClass::clearClipRect();

描画クリップ矩形を設定します。

`setClipRect(const Rect &rect)` では矩形構造体で描画範囲を指定します。
`setClipRect(int x, int y, int w, int h)` では左上座標とサイズを個別に指定します。
クリップ範囲の外側には描画されません。

`clearClipRect()` を呼ぶとクリップ矩形が解除され、描画先全体に描画できる状態に戻ります。

devColor
--------------------------------------------------------------------------------

.. code-block:: cpp

	xmc::DevColor xmc::Graphics2DClass::devColor(int r, int g, int b, int a = 255);
	xmc::DevColor xmc::Graphics2DClass::devColor(xmc::Colors color);

描画対象のピクセルフォーマットに合わせて色を変換します。

`devColor(int r, int g, int b, int a = 255)` では 8bit 整数の RGBA 値を指定します。
各成分は内部で描画先のピクセルフォーマットに合わせて変換されます。

`devColor(xmc::Colors color)` ではあらかじめ定義された色定数を使用できます。

戻り値は、そのまま描画関数に渡せる `xmc::DevColor` です。

devColorHSV
--------------------------------------------------------------------------------

.. code-block:: cpp

	xmc::DevColor xmc::Graphics2DClass::devColorHSV(int h, int s, int v);

HSV 色空間で色を指定し、描画対象のピクセルフォーマットに合わせて変換します。

`h` は色相を 0〜359 の整数で指定します。範囲外の値は自動的に正規化されます。
`s` は彩度、`v` は明度をそれぞれ 0〜255 の整数で指定します。

戻り値は、そのまま描画関数に渡せる `xmc::DevColor` です。

clear
--------------------------------------------------------------------------------

.. code-block:: cpp

	void xmc::Graphics2DClass::clear(xmc::DevColor color);

現在のクリップ範囲全体を `color` で塗りつぶします。

setPixel
--------------------------------------------------------------------------------

.. code-block:: cpp

	void xmc::Graphics2DClass::setPixel(int x, int y, xmc::DevColor color);

1 ピクセルを描画します。

fillRect
--------------------------------------------------------------------------------

.. code-block:: cpp

	void xmc::Graphics2DClass::fillRect(xmc::Rect dstRect, xmc::DevColor color);
	void xmc::Graphics2DClass::fillRect(int x, int y, int w, int h, xmc::DevColor color);

矩形内部を塗りつぶします。
`xmc::Rect` 構造体で指定する版と、座標とサイズを個別に指定する版があります。

drawRect
--------------------------------------------------------------------------------

.. code-block:: cpp

	void xmc::Graphics2DClass::drawRect(xmc::Rect dstRect, xmc::DevColor color);
	void xmc::Graphics2DClass::drawRect(int x, int y, int w, int h, xmc::DevColor color);

矩形の枠線のみを描画します。
`xmc::Rect` 構造体で指定する版と、座標とサイズを個別に指定する版があります。

fillEllipse
--------------------------------------------------------------------------------

.. code-block:: cpp

	void xmc::Graphics2DClass::fillEllipse(xmc::Rect dstRect, xmc::DevColor color);
	void xmc::Graphics2DClass::fillEllipse(int x, int y, int w, int h, xmc::DevColor color);

`dstRect` で指定された矩形に内接する楕円を `color` で塗りつぶします。
`xmc::Rect` 構造体で指定する版と、座標とサイズを個別に指定する版があります。

fillPolygon
--------------------------------------------------------------------------------

.. code-block:: cpp

	void xmc::Graphics2DClass::fillPolygon(const xmc::vec2i *vertices, int numVertices, xmc::DevColor color);

多角形の内部を `color` で塗りつぶします。

`vertices` には頂点座標の配列先頭を指定します。
`numVertices` には頂点数を指定します。
最後の頂点と最初の頂点は自動的に接続されます。

描画は現在のクリップ矩形の範囲内に制限されます。

fillSmokeRect
--------------------------------------------------------------------------------

.. code-block:: cpp

	void xmc::Graphics2DClass::fillSmokeRect(xmc::Rect dstRect, bool white = false);
	void xmc::Graphics2DClass::fillSmokeRect(int x, int y, int w, int h, bool white = false);

白または黒ベースのスモーク表現を描画する補助関数です。
`white` を `true` にすると各ピクセルを現在の色と白の中間色で塗りつぶし、
`false` の場合は現在の色と黒の中間色で塗りつぶします。

drawLine
--------------------------------------------------------------------------------

.. code-block:: cpp

	void xmc::Graphics2DClass::drawLine(int x1, int y1, int x2, int y2, xmc::DevColor color);

2 点間に直線を描画します。

drawImage
--------------------------------------------------------------------------------

.. code-block:: cpp

	void drawImage(const xmc::Sprite &image, int dx, int dy, int w, int h, int sx, int sy, const xmc::TextRenderArgs &tra);
	void drawImage(const xmc::Sprite &image, int dx, int dy, int w, int h, int sx, int sy);
	void drawImage(const xmc::Sprite &image, int dx, int dy);

Sprite を描画します。
転送元矩形を指定する版と、画像全体を描画する簡易版があります。

`image` には描画元 Sprite を指定します。
`dx`, `dy` は描画先の左上座標です。

完全版では、`w`, `h` にコピーサイズ、`sx`, `sy` に描画元 Sprite 内の開始座標を指定します。
`tra` には前景色・背景色・描画フラグを指定し、1bit 画像やフォント画像の描画方法を制御できます。

2 引数版は画像全体をそのまま描画し、7 引数版は `tra` に既定値を使って部分描画します。

setFont
--------------------------------------------------------------------------------

.. code-block:: cpp

	void xmc::Graphics2DClass::setFont(const GFXfont *font);
	void xmc::Graphics2DClass::setFont(const GFXfont *font, int size);

文字描画に使用するフォントを設定します。
サイズ付きオーバーロードでは `size` に拡大倍率を指定します。

setFontSize
--------------------------------------------------------------------------------

.. code-block:: cpp

	void xmc::Graphics2DClass::setFontSize(int size);

現在設定されているフォントの描画サイズ（拡大倍率）を設定します。

setCursor
--------------------------------------------------------------------------------

.. code-block:: cpp

	void xmc::Graphics2DClass::setCursor(int x, int y);

文字列描画の開始位置を設定します。

setTextColor
--------------------------------------------------------------------------------

.. code-block:: cpp

	void xmc::Graphics2DClass::setTextColor(xmc::DevColor fg);
	void xmc::Graphics2DClass::setTextColor(xmc::DevColor fg, xmc::DevColor bg);

文字色を設定します。
`setTextColor(fg)` は前景色のみを設定し、
`setTextColor(fg, bg)` は前景色と背景色の両方を設定します。

drawString
--------------------------------------------------------------------------------

.. code-block:: cpp

	void xmc::Graphics2DClass::drawString(const char *str);

現在のフォント設定、文字色、カーソル位置を使って文字列を描画します。

FrameBuffer
================================================================================

xmc::FrameBufferFlags
--------------------------------------------------------------------------------

.. csv-table:: xmc::FrameBufferFlags の値
	 :header: "値", "説明"

	 "xmc::FrameBufferFlags::SHOW_STATUS_BAR", "ステータスバー表示"
	 "xmc::FrameBufferFlags::SHOW_BATTERY_LEVEL", "バッテリー表示"
	 "xmc::FrameBufferFlags::SHOW_FPS", "FPS 表示"
	 "xmc::FrameBufferFlags::SHOW_DEBUG_INFO", "デバッグ情報表示"
	 "xmc::FrameBufferFlags::DEFAULT", "標準フラグ"

コンストラクタ
--------------------------------------------------------------------------------

.. code-block:: cpp

	xmc::FrameBuffer xmc::createFrameBuffer(xmc::PixelFormat fmt, bool doubleBuffered = false, int width = xmc::display::WIDTH, int height = xmc::display::HEIGHT);

フレームバッファを生成します。

`fmt` にはバッファのピクセルフォーマットを指定します。
`doubleBuffered` を `true` にするとダブルバッファリングが有効になります。
`width`, `height` を省略した場合はディスプレイサイズが使用されます。

戻り値として、描画制御と画面転送を扱う `xmc::FrameBuffer` オブジェクトを返します。

isDoubleBuffered
--------------------------------------------------------------------------------

.. code-block:: cpp

	bool xmc::FrameBufferClass::isDoubleBuffered() const;

ダブルバッファリングが有効かどうかを返します。
有効な場合は `true`、シングルバッファの場合は `false` を返します。

getWidth / getHeight
--------------------------------------------------------------------------------

.. code-block:: cpp

	int xmc::FrameBufferClass::getWidth() const;
	int xmc::FrameBufferClass::getHeight() const;

フレームバッファのサイズを返します。
戻り値はそれぞれピクセル単位の幅と高さです。

getPixelFormat
--------------------------------------------------------------------------------

.. code-block:: cpp

	xmc::PixelFormat xmc::FrameBufferClass::getPixelFormat() const;

フレームバッファのピクセルフォーマットを返します。
戻り値は `xmc::PixelFormat` 列挙型です。

getFrontBuffer / getBackBuffer
--------------------------------------------------------------------------------

.. code-block:: cpp

	xmc::Sprite xmc::FrameBufferClass::getFrontBuffer() const;
	xmc::Sprite xmc::FrameBufferClass::getBackBuffer() const;

フロントバッファとバックバッファを取得します。

`getFrontBuffer()` は現在表示中のバッファを返します。
`getBackBuffer()` は次フレーム描画用のバッファを返します。

シングルバッファ構成では、両者が同じ実体を指す場合があります。

createGraphics
--------------------------------------------------------------------------------

.. code-block:: cpp

	xmc::Graphics2D xmc::FrameBufferClass::createGraphics() const;

バックバッファを描画先に設定した `Graphics2D` オブジェクトを生成して返します。
フレームバッファへ 2D 描画を行う際の基本的な入口として使用します。

beginRender / endRender
--------------------------------------------------------------------------------

.. code-block:: cpp

	XmcStatus xmc::FrameBufferClass::beginRender();
	XmcStatus xmc::FrameBufferClass::endRender(bool transferToDisplay = true);

1 フレーム分の描画区間を開始・終了します。

`beginRender()` は描画開始前の準備を行います。
`endRender()` は描画終了処理を行い、`transferToDisplay` が `true` の場合は描画内容をディスプレイへ転送します。

戻り値はいずれも `XmcStatus` で、正常に処理できた場合は `XMC_OK` が返ります。

enableFlag / disableFlag
--------------------------------------------------------------------------------

.. code-block:: cpp

	void xmc::FrameBufferClass::enableFlag(xmc::FrameBufferFlags flag);
	void xmc::FrameBufferClass::disableFlag(xmc::FrameBufferFlags flag);

フレームバッファの表示補助機能を有効化・無効化します。

`flag` には `xmc::FrameBufferFlags` の値を指定します。
ステータスバー、バッテリー残量、FPS 表示などの付加表示を切り替える用途で使用します。

FpsKeeper
================================================================================

描画ループを目標 FPS に同期するための補助クラスです。

コンストラクタ
--------------------------------------------------------------------------------

.. code-block:: cpp

	xmc::FpsKeeper::FpsKeeper(float fps, uint32_t maxJitter = 5000);

`fps` には目標フレームレートを指定します。
`maxJitter` は遅延許容値をマイクロ秒単位で指定します。

`waitVsync()` 呼び出し時に目標時刻まで待機し、
遅延が `maxJitter` を超えた場合は内部の同期時刻を現在時刻に再同期します。

setTargetFps
--------------------------------------------------------------------------------

.. code-block:: cpp

	void xmc::FpsKeeper::setTargetFps(float fps);

実行中に目標 FPS を変更します。

waitVsync
--------------------------------------------------------------------------------

.. code-block:: cpp

	void xmc::FpsKeeper::waitVsync();

次フレームの目標タイミングまで待機します。

内部では、前回までの基準時刻と目標 FPS から次回時刻を計算します。
処理が遅延している場合はフレームスキップ状態を更新し、
必要に応じて同期時刻を補正します。

isFrameSkipping
--------------------------------------------------------------------------------

.. code-block:: cpp

	bool xmc::FpsKeeper::isFrameSkipping() const;

現在フレームをスキップすべき状態かどうかを返します。

戻り値が `true` のフレームでは描画負荷の高い処理を省略し、
`false` のフレームで通常描画を行うことで、遅延からの回復を支援できます。

LineGraph
================================================================================

描画用の折れ線グラフデータを保持・描画するテンプレートクラスです。

xmc::createLineGraph
--------------------------------------------------------------------------------

.. code-block:: cpp

	template <typename TValue>
	xmc::LineGraph<TValue> xmc::createLineGraph(int capacity, XmcHeapCap heapCap = XMC_HEAP_CAP_SPIRAM);

`LineGraph` インスタンスを生成します。

`TValue` にはグラフのデータ型を指定します（例：`float`, `uint16_t`）。
`capacity` には保持するデータ点数を指定します。
`heapCap` にはデータバッファを確保する RAM の種類を指定します。

xmc::LineGraphClass
--------------------------------------------------------------------------------

LineGraph の実体クラスです。`xmc::LineGraph<TValue>` は `std::shared_ptr<xmc::LineGraphClass<TValue>>` の別名です。

clear
--------------------------------------------------------------------------------

.. code-block:: cpp

	void xmc::LineGraphClass<TValue>::clear();

グラフデータをすべて消去します。

push
--------------------------------------------------------------------------------

.. code-block:: cpp

	void xmc::LineGraphClass<TValue>::push(TValue value);

グラフにデータ点を追加します。
データ点数が `capacity` に達している場合は、最も古いデータが破棄されます。

setYRange / getYRange
--------------------------------------------------------------------------------

.. code-block:: cpp

	void xmc::LineGraphClass<TValue>::setYRange(TValue min, TValue max);
	void xmc::LineGraphClass<TValue>::getYRange(TValue *min = nullptr, TValue *max = nullptr);

グラフの Y 軸の表示範囲を設定・取得します。

`setYRange()` の `min`, `max` にはそれぞれ最小値・最大値を指定します。
`getYRange()` では `min`, `max` が `nullptr` でない場合に対応する値を書き込みます。

render
--------------------------------------------------------------------------------

.. code-block:: cpp

	void xmc::LineGraphClass<TValue>::render(xmc::Graphics2D &gfx, int x, int y, int w, int h, xmc::DevColor color);

グラフを描画します。

`gfx` には描画先の `Graphics2D` を指定します。
`x`, `y` は描画領域の左上座標、`w`, `h` は描画領域のサイズです。
`color` には折れ線の色を指定します。

データ点が 2 点未満の場合、または Y 軸範囲が 0 の場合は何も描画されません。

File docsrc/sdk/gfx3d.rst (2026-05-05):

3D グラフィックス API
################################################################################

概要
================================================================================

3D 描画は次の流れで使用します。

1. `Graphics3D` を生成して描画先を設定する
2. `Scene3D` / `Node3D` / `Mesh3D` / `Primitive3D` を組み立てる
3. `beginRender()` → `render()` → `endRender()` で 1 フレーム描画する

描画制御
================================================================================

xmc::ClearTarget
--------------------------------------------------------------------------------

`beginRender()` 時にクリア対象を指定する列挙型です。

.. csv-table:: xmc::ClearTarget の値
	 :header: "値", "説明"

	 "xmc::ClearTarget::STACK", "内部状態スタックをクリア"
	 "xmc::ClearTarget::DEPTH", "深度バッファをクリア"
	 "xmc::ClearTarget::ALL", "全クリア"

xmc::RenderFlags3D
--------------------------------------------------------------------------------

3D レンダリングの機能フラグです。

.. csv-table:: xmc::RenderFlags3D の主な値
	 :header: "値", "説明"

	 "xmc::RenderFlags3D::VERTEX_COLOR", "頂点カラーを使用"
	 "xmc::RenderFlags3D::VERTEX_NORMAL", "頂点法線を使用"
	 "xmc::RenderFlags3D::GOURAUD_SHADING", "グーローシェーディング"
	 "xmc::RenderFlags3D::LIGHTING", "ライティング"
	 "xmc::RenderFlags3D::COLOR_TEXTURE", "テクスチャカラー"
	 "xmc::RenderFlags3D::Z_TEST", "深度テスト"
	 "xmc::RenderFlags3D::Z_UPDATE", "深度バッファ更新"
	 "xmc::RenderFlags3D::DEFAULT", "標準設定"

xmc::ParallelMode3D
--------------------------------------------------------------------------------

並列レンダリングモードです。

.. csv-table:: xmc::ParallelMode3D の値
	 :header: "値", "説明"

	 "xmc::ParallelMode3D::NONE", "並列化なし"
	 "xmc::ParallelMode3D::INTERLACE", "インターレース分担"
	 "xmc::ParallelMode3D::PIPELINE", "パイプライン分担"

シーン構築
================================================================================

xmc::createScene3D
--------------------------------------------------------------------------------

.. code-block:: cpp

	xmc::Scene3D xmc::createScene3D();

シーンを生成します。`Scene3DClass::rootNodes` または `addNode()` でノードを追加します。

戻り値として空の `xmc::Scene3D` オブジェクトを返します。
複数のルートノードを持つシーンを構築したい場合の起点になります。

xmc::createNode3D
--------------------------------------------------------------------------------

.. code-block:: cpp

	xmc::Node3D xmc::createNode3D(xmc::Mesh3D mesh, xmc::mat4 transform = xmc::mat4::identity());

メッシュとローカル変換行列からノードを生成します。

`mesh` には描画対象メッシュを指定します。
`transform` にはノードに適用するローカル変換行列を指定します。

戻り値として `xmc::Node3D` オブジェクトを返します。
子ノードを `children` に追加することでシーングラフを構築できます。

xmc::createMesh3D
--------------------------------------------------------------------------------

.. code-block:: cpp

	xmc::Mesh3D xmc::createMesh3D(std::vector<xmc::Primitive3D> &&prims);

プリミティブ集合からメッシュを生成します。

`prims` にはメッシュを構成するプリミティブ列を指定します。
戻り値として `xmc::Mesh3D` を返します。

xmc::createCube / createColoredCube / createSphere
--------------------------------------------------------------------------------

.. code-block:: cpp

	xmc::Mesh3D xmc::createCube(float s = 1.0f, bool uv = true);
	xmc::Mesh3D xmc::createColoredCube(float s = 1.0f);
	xmc::Mesh3D xmc::createSphere(float radius = 1.0f, int segments = 12, int rings = 6, xmc::colorf col = {1.0f, 1.0f, 1.0f, 1.0f});

定型メッシュを生成します。

`createCube()` の `s` は立方体の一辺の長さです。
`uv` を `true` にすると UV 座標付きメッシュを生成します。

`createColoredCube()` は頂点色付き立方体を返します。

`createSphere()` では `radius` に半径、`segments` に経度方向分割数、`rings` に緯度方向分割数、`col` に球の基本色を指定します。

いずれも戻り値は `xmc::Mesh3D` です。

プリミティブとマテリアル
================================================================================

xmc::createPrimitive3D
--------------------------------------------------------------------------------

.. code-block:: cpp

	xmc::Primitive3D xmc::createPrimitive3D(
			xmc::PrimitiveMode mode,
			xmc::Vec3Buffer pos,
			xmc::Vec3Buffer norm,
			xmc::ColorBuffer col,
			xmc::Vec2Buffer uv = nullptr,
			xmc::IndexBuffer idx = nullptr,
			xmc::Material3D mat = nullptr);

1 つの描画プリミティブを生成します。

`mode` には描画トポロジを指定します。
`pos` は頂点位置配列、`norm` は法線配列、`col` は頂点カラー配列です。
`uv` はテクスチャ座標、`idx` はインデックス配列、`mat` はマテリアルを指定します。

使用しない属性は `nullptr` を指定できますが、レンダリングフラグやマテリアル設定と整合している必要があります。
戻り値は `xmc::Primitive3D` です。

xmc::createMaterial3D
--------------------------------------------------------------------------------

.. code-block:: cpp

	xmc::Material3D xmc::createMaterial3D();

マテリアルを生成します。

戻り値として、各種見た目設定を書き込むための `xmc::Material3D` オブジェクトを返します。

xmc::MaterialFlags3D
--------------------------------------------------------------------------------

.. csv-table:: xmc::MaterialFlags3D の値
	 :header: "値", "説明"

	 "xmc::MaterialFlags3D::HAS_BASE_COLOR", "ベースカラーを有効化"
	 "xmc::MaterialFlags3D::DOUBLE_SIDED", "両面描画"
	 "xmc::MaterialFlags3D::ENVIRONMENT_MAPPED", "環境マップ反射"

xmc::Material3DClass の主なメンバー
--------------------------------------------------------------------------------

.. csv-table:: xmc::Material3DClass の主なメンバー
	 :header: "型", "メンバー", "説明"

	 "xmc::MaterialFlags3D", "flags", "マテリアルフラグ"
	 "xmc::colorf", "baseColor", "ベースカラー"
	 "xmc::Sprite", "colorTexture", "カラーテクスチャ"
	 "xmc::VertexShader *", "vertexShader", "頂点シェーダ"

属性バッファ
================================================================================

.. code-block:: cpp

	xmc::Vec2Buffer xmc::createVec2Buffer(int size, XmcHeapCap caps = XMC_HEAP_CAP_SPIRAM);
	xmc::Vec2Buffer xmc::createVec2Buffer(xmc::vec2 *data, int size, bool autoFree = false);

	xmc::Vec3Buffer xmc::createVec3Buffer(int size, XmcHeapCap caps = XMC_HEAP_CAP_SPIRAM);
	xmc::Vec3Buffer xmc::createVec3Buffer(xmc::vec3 *data, int size, bool autoFree = false);

	xmc::ColorBuffer xmc::createColorBuffer(int size, XmcHeapCap caps = XMC_HEAP_CAP_SPIRAM);
	xmc::ColorBuffer xmc::createColorBuffer(xmc::colorf *data, int size, bool autoFree = false);

	xmc::IndexBuffer xmc::createIndexBuffer(int size, XmcHeapCap caps = XMC_HEAP_CAP_SPIRAM);
	xmc::IndexBuffer xmc::createIndexBuffer(uint16_t *data, int size, bool autoFree = false);

頂点属性配列を生成します。

サイズ指定版では指定要素数のバッファを新規確保して返します。
`caps` には確保先 RAM の特性を指定します。

ポインタ指定版では既存配列を属性バッファとしてラップします。
`data` は配列先頭、`size` は要素数です。
`autoFree` を `true` にするとオブジェクト破棄時に `data` が自動解放されます。

Graphics3D
================================================================================

xmc::createGraphics3D
--------------------------------------------------------------------------------

.. code-block:: cpp

	xmc::Graphics3D xmc::createGraphics3D(int width, int height, uint32_t stackSize = 16);

3D 描画コンテキストを生成します。

`width`, `height` には描画先サイズをピクセル単位で指定します。
`stackSize` は変換状態を保持するスタック深さです。

戻り値として `xmc::Graphics3D` オブジェクトを返します。

setTarget
--------------------------------------------------------------------------------

.. code-block:: cpp

	void xmc::Graphics3DClass::setTarget(xmc::Sprite target);
	void xmc::Graphics3DClass::setTarget(xmc::Sprite target, xmc::Rect viewport);

3D 描画先 Sprite を設定します。

`target` には描画先 Sprite を指定します。
`viewport` 指定版では、Sprite 内の描画領域を矩形で指定できます。
ビューポート省略版では Sprite 全体が描画領域になります。

setParallelMode / getParallelMode
--------------------------------------------------------------------------------

.. code-block:: cpp

	void xmc::Graphics3DClass::setParallelMode(xmc::ParallelMode3D mode);
	xmc::ParallelMode3D xmc::Graphics3DClass::getParallelMode() const;

並列レンダリングモードを設定・取得します。

`mode` には `xmc::ParallelMode3D` の値を指定します。
`getParallelMode()` は現在の並列レンダリングモードを返します。

setFlags / enableFlags / disableFlags
--------------------------------------------------------------------------------

.. code-block:: cpp

	void xmc::Graphics3DClass::setFlags(xmc::RenderFlags3D flags);
	void xmc::Graphics3DClass::enableFlags(xmc::RenderFlags3D flags);
	void xmc::Graphics3DClass::disableFlags(xmc::RenderFlags3D flags);

レンダリング機能フラグを設定します。

`setFlags()` はフラグ全体を置き換えます。
`enableFlags()` と `disableFlags()` は指定したフラグだけを個別に有効化・無効化します。

setBlendMode
--------------------------------------------------------------------------------

.. code-block:: cpp

	void xmc::Graphics3DClass::setBlendMode(xmc::BlendMode mode);

ブレンドモードを設定します。
`mode` には `xmc::BlendMode` の値を指定します。

setEnvironmentLight / setParallelLight
--------------------------------------------------------------------------------

.. code-block:: cpp

	void xmc::Graphics3DClass::setEnvironmentLight(const xmc::colorf &color);
	void xmc::Graphics3DClass::setParallelLight(const xmc::vec3 &dir, const xmc::colorf &color);

ライティング条件を設定します。

`setEnvironmentLight()` は環境光の色を設定します。
`setParallelLight()` は平行光源の方向 `dir` と色 `color` を設定します。

setProjection / setOrthoProjection / setPerspectiveProjection
--------------------------------------------------------------------------------------------

.. code-block:: cpp

	void xmc::Graphics3DClass::setProjection(const xmc::mat4 &mat);
	void xmc::Graphics3DClass::setOrthoProjection(float left, float right, float bottom, float top, float near = 0.01f, float far = 100.0f);
	void xmc::Graphics3DClass::setPerspectiveProjection(float fovY, float aspect, float near = 0.01f, float far = 100.0f);

投影行列を設定します。

`setProjection()` は投影行列を直接設定します。
`setOrthoProjection()` は平行投影、`setPerspectiveProjection()` は透視投影を簡易に設定する補助関数です。

setViewMatrix / lookAt
--------------------------------------------------------------------------------

.. code-block:: cpp

	void xmc::Graphics3DClass::setViewMatrix(const xmc::mat4 &mv);
	void xmc::Graphics3DClass::lookAt(const xmc::vec3 &eye, const xmc::vec3 &focus, const xmc::vec3 &up);

ビュー行列を設定します。

`setViewMatrix()` はビュー行列を直接設定します。
`lookAt()` は視点 `eye`、注視点 `focus`、上方向 `up` からビュー行列を生成して設定します。

pushState / popState
--------------------------------------------------------------------------------

.. code-block:: cpp

	void xmc::Graphics3DClass::pushState();
	void xmc::Graphics3DClass::popState();

変換状態スタックを保存・復元します。
階層構造をたどりながら個別の変換を適用したい場合に使用します。

loadIdentity / loadMatrix / transform
--------------------------------------------------------------------------------

.. code-block:: cpp

	void xmc::Graphics3DClass::loadIdentity();
	void xmc::Graphics3DClass::loadMatrix(const xmc::mat4 &m);
	void xmc::Graphics3DClass::transform(const xmc::mat4 &t);

現在のモデル変換行列を設定します。

`loadIdentity()` は単位行列へ初期化します。
`loadMatrix()` は行列を直接設定します。
`transform()` は現在行列に変換行列を乗算します。

translate / rotate / scale
--------------------------------------------------------------------------------

.. code-block:: cpp

	void xmc::Graphics3DClass::translate(const xmc::vec3 &t);
	void xmc::Graphics3DClass::translate(float x, float y, float z);
	void xmc::Graphics3DClass::rotate(const xmc::quat &q);
	void xmc::Graphics3DClass::rotate(float pitch, float yaw, float roll);
	void xmc::Graphics3DClass::rotate(const xmc::vec3 &axis, float angle);
	void xmc::Graphics3DClass::scale(const xmc::vec3 &s);
	void xmc::Graphics3DClass::scale(float s);

現在のモデル変換に平行移動、回転、拡大縮小を適用します。
オーバーロードによりベクトル指定と成分指定の両方を使用できます。

beginRender / endRender
--------------------------------------------------------------------------------

.. code-block:: cpp

	void xmc::Graphics3DClass::beginRender(xmc::ClearTarget target = xmc::ClearTarget::ALL);
	void xmc::Graphics3DClass::endRender();

1 フレーム分の 3D 描画を開始・終了します。

`beginRender()` の `target` にはクリア対象を指定します。
通常は既定値の `xmc::ClearTarget::ALL` を使用します。

render
--------------------------------------------------------------------------------

.. code-block:: cpp

	void xmc::Graphics3DClass::render(const xmc::Scene3D &scene);
	void xmc::Graphics3DClass::render(const xmc::Node3D &node);
	void xmc::Graphics3DClass::render(const xmc::Mesh3D &mesh);
	void xmc::Graphics3DClass::render(const xmc::Primitive3D &prim);

シーンまたは描画要素をレンダリングします。

大きなシーン全体を描く場合は `Scene3D` を、個別に制御したい場合は `Node3D`、`Mesh3D`、`Primitive3D` を直接渡します。
`beginRender()` と `endRender()` の間で呼び出します。

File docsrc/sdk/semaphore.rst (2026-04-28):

セマフォ API
################################################################################

概要
================================================================================

`xmc::Semaphore` は、スレッド間またはコア間で共有リソースへのアクセスを同期するためのバイナリセマフォです。

コンストラクタ直後は利用可能状態 (トークン保持) で初期化されます。

Semaphore クラス
================================================================================

xmc::Semaphore::Semaphore
--------------------------------------------------------------------------------

.. code-block:: cpp

	xmc::Semaphore::Semaphore();

セマフォを生成します。

内部リソース確保に失敗した場合、セマフォは未初期化状態になります。

xmc::Semaphore::~Semaphore
--------------------------------------------------------------------------------

.. code-block:: cpp

	xmc::Semaphore::~Semaphore();

セマフォを破棄し、内部リソースを解放します。

xmc::Semaphore::isInitialized
--------------------------------------------------------------------------------

.. code-block:: cpp

	bool xmc::Semaphore::isInitialized() const;

セマフォが初期化済みかどうかを返します。

初期化成功時は `true`、失敗時は `false` です。

xmc::Semaphore::take
--------------------------------------------------------------------------------

.. code-block:: cpp

	void xmc::Semaphore::take();

セマフォを取得します。

利用可能になるまでブロッキングします。
未初期化状態では何も行いません。

xmc::Semaphore::tryTake
--------------------------------------------------------------------------------

.. code-block:: cpp

	bool xmc::Semaphore::tryTake();

非ブロッキングでセマフォ取得を試みます。

取得に成功した場合は `true`、取得できなかった場合は `false` を返します。
未初期化状態でも `false` を返します。

xmc::Semaphore::give
--------------------------------------------------------------------------------

.. code-block:: cpp

	void xmc::Semaphore::give();

セマフォを解放します。

`take()` または `tryTake()` で取得したセマフォを他の処理へ譲渡できる状態に戻します。
未初期化状態では何も行いません。

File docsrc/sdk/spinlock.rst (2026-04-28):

スピンロック API
################################################################################

概要
================================================================================

`xmc::SpinLock` は、短時間のクリティカルセクションを保護するための排他制御プリミティブです。

主に、コア間または割り込みコンテキストをまたぐ共有データの保護に使用します。

SpinLock クラス
================================================================================

xmc::SpinLock::SpinLock
--------------------------------------------------------------------------------

.. code-block:: cpp

	xmc::SpinLock::SpinLock();

スピンロックを生成します。

内部リソースの確保に失敗した場合、ロックは未初期化状態になります。

xmc::SpinLock::~SpinLock
--------------------------------------------------------------------------------

.. code-block:: cpp

	xmc::SpinLock::~SpinLock();

スピンロックを破棄し、内部リソースを解放します。

xmc::SpinLock::get
--------------------------------------------------------------------------------

.. code-block:: cpp

	void xmc::SpinLock::get();

ロックを取得します。

他の実行コンテキストが保持中の場合は、取得可能になるまで待機します。
未初期化状態では何も行いません。

xmc::SpinLock::release
--------------------------------------------------------------------------------

.. code-block:: cpp

	void xmc::SpinLock::release();

取得済みロックを解放します。

`get()` で保護したクリティカルセクションの終端で呼び出します。
未初期化状態では何も行いません。

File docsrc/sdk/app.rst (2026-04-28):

Xiamocon アプリケーションの基本構造
################################################################################

Xiamocon アプリケーションは 4 つの関数から構成されます。

.. csv-table:: Xiamocon アプリケーションの関数
   :header: "関数", "説明"

   "xmcAppGetConfig", "アプリケーションのコンフィグレーション情報を返す関数"
   "xmcAppSetup", "アプリケーションのセットアップを行う関数。"
   "xmcAppLoop", "アプリケーションのメインループ関数。"
   "xmcAppTerminate", "アプリケーションの終了処理を行う関数。"

xmcAppGetConfig
================================================================================

プロトタイプ宣言:

.. code-block:: c++

    xmc::AppConfig xmcAppGetConfig(void)

xmcAppGetConfig 関数は、アプリケーションのコンフィグレーション情報を返す関数です。
xmc::AppConfig 構造体には、システムを初期化するための基本的なコンフィグレーション情報が含まれます。

通常は getDefaultAppConfig() 関数を使用してデフォルトのコンフィグレーションを取得し、必要に応じて値を変更してから返します。

.. csv-table:: xmc::AppConfig のメンバー
   :header: "型","メンバー", "説明"

   "xmc::PixelFormat","displayPixelFormat", "ディスプレイのピクセルフォーマットを指定する列挙型。"
   "bool","speakerEnabled", "スピーカーの有効/無効を指定するブール値。"
   "xmc::audio::SampleFormat","speakerSampleFormat", "スピーカーのサンプルフォーマットを指定する列挙型。"
   "uint32_t","speakerSampleRateHz", "スピーカーのサンプルレートを指定する整数。"
   "uint32_t","speakerLatencySamples", "スピーカーのレイテンシをサンプル単位で指定する整数。"

全てのコンフィグレーションをデフォルト値のまま使用する場合は、xmcAppGetConfig 関数の定義は省略することができます。

displayPixelFormat
--------------------------------------------------------------------------------

ディスプレイのピクセルフォーマットを xmc::PixelFormat 列挙型で指定します。Xiamocon SDK では、現在のところ次のピクセルフォーマットがサポートされます。

.. csv-table:: xmc::PixelFormat 列挙型の値
   :header: "値", "説明"

   "xmc::PixelFormat::RGB444", "12 ビット RGB フォーマット。赤、緑、青がそれぞれ 4 ビットで表されます。"
   "xmc::PixelFormat::RGB565 (デフォルト)", "16 ビット RGB フォーマット。赤が 5 ビット、緑が 6 ビット、青が 5 ビットで表されます。"   

RGB444 フォーマットはメモリの使用量抑制とディスプレイ更新速度の向上に貢献しますが、
ピクセル処理が複雑になるため、レンダリングのパフォーマンスが低下する可能性があります。

speakerEnabled
--------------------------------------------------------------------------------

スピーカーの有効/無効を指定するブール値です。
true の場合、プラットフォーム側のオーディオ出力機能が有効になります。

プラットフォーム側の機能を使用せず独自にオーディオ出力を実装する場合は false を指定します。

speakerSampleFormat
--------------------------------------------------------------------------------

スピーカーのサンプルフォーマットを xmc::audio::SampleFormat 列挙型で指定します。
Xiamocon SDK では、現在のところ次のサンプルフォーマットがサポートされます。

.. csv-table:: xmc::audio::SampleFormat 列挙型の値
   :header: "値", "説明"

   "xmc::audio::SampleFormat::LINEAR_PCM_U8_MONO", "8 ビット符号なし整数フォーマット。"
   "xmc::audio::SampleFormat::LINEAR_PCM_S16_MONO (デフォルト)", "16 ビット符号付き整数フォーマット。"

LINEAR_PCM_U8_MONO フォーマットは使用するメモリは少なくなりますが、
プラットフォーム側で 16 ビット符号付きへ変換されるため、若干のパフォーマンス上のオーバーヘッドがあります。

speakerSampleRateHz
--------------------------------------------------------------------------------

スピーカーのサンプリングレートを指定します。単位はヘルツ (Hz) です。

基本的にこの値は変更しないで下さい。
サンプリングレートはプラットフォーム側の PDM 変換処理と密接に関係するため、
この値を変更するとオーディオ出力が正常に行えなくなったり、ノイズが発生する可能性があります。

RP2350 では 20.833 kHz、ESP32S3 では 24 kHz がデフォルトで使用されます。

speakerLatencySamples
--------------------------------------------------------------------------------

スピーカーのレイテンシをサンプル数で指定します。

この値を小さくするとレイテンシが小さくなりますが、
グラフィックス処理等でシステムに負荷がかかると音が途切れやすくなります。

デフォルトでは 1024 サンプルが使用されます。

xmcAppSetup
================================================================================

プロトタイプ宣言:

.. code-block:: c++

   void xmcAppSetup(void)

xmcAppSetup 関数は、アプリケーションのセットアップを行う関数です。
この関数内で各種リソースの確保や外部デバイスの初期化などを行います。

戻り値はありません。

この関数内で行う処理が何も無い場合は、関数の定義を省略することができます。

xmcAppLoop
================================================================================

プロトタイプ宣言:

.. code-block:: c++

   void xmcAppLoop(void)

xmcAppLoop 関数は、アプリケーションのメインループ関数です。
この関数は、アプリケーションが実行されている間、繰り返し呼び出されます。

キーパッドの入力処理、オーディオ出力の維持、バッテリー監視などは
プラットフォーム側で行われるため、この関数内で行う必要はありません。

この関数内では、アプリケーションのロジックやグラフィックス処理などを実装します。

戻り値はありません。

xmcAppTerminate
================================================================================

プロトタイプ宣言:

.. code-block:: c++

   XmcStatus xmcAppTerminate(xmc::system::ShutdownReason reason)

xmcAppTerminate 関数は、アプリケーションの終了処理を行う関数です。

`reason` には終了要求の理由が渡されます。
理由の種類は `xmc::system::ShutdownReason` 列挙型で表されます。

.. csv-table:: xmc::system::ShutdownReason の値
   :header: "値", "説明"

   "xmc::system::ShutdownReason::POWER_SWITCH", "電源ボタン操作による終了要求"
   "xmc::system::ShutdownReason::LOW_BATTERY", "低電圧検知による終了要求"
   "xmc::system::ShutdownReason::REQUESTED_BY_APPLICATION", "アプリケーションからの終了要求"

システムが電源ボタンが押されたことを検知するとこの関数が呼び出されます。
この関数内で、確保したリソースの解放や外部デバイスの終了処理などを行います。

この関数が XMC_OK を返すとシステムの電源が切れます。

XMC_OK 以外を返すことでシャットダウンをキャンセルすることができますが、
I/O 処理など、どうしても中断できない処理を行っている場合に限るべきです。

この関数内で行うことが何も無く、単に XMC_OK を返すだけの場合は、関数の定義を省略することができます。

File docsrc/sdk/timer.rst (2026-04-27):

タイマー API
################################################################################

概要
================================================================================

タイマー API では、周期コールバックを行う `RepeatingTimer` と、
時刻取得・スリープ関数を提供します。

型
================================================================================

xmc::TimerCallback
--------------------------------------------------------------------------------

.. code-block:: cpp

	using xmc::TimerCallback = bool (*)(void *context);

周期タイマーのコールバック型です。
戻り値が `true` の場合は継続、`false` の場合はタイマーを停止します。

引数 `context` には `startMs()` 呼び出し時に渡したポインタがそのまま渡されます。

RepeatingTimer
================================================================================

xmc::RepeatingTimer::startMs
--------------------------------------------------------------------------------

.. code-block:: cpp

	XmcStatus xmc::RepeatingTimer::startMs(uint32_t intervalMs, xmc::TimerCallback cb, void *context);

指定周期 [ms] でコールバックを呼び出すタイマーを開始します。

`intervalMs` には呼び出し周期、`cb` にはコールバック関数、`context` にはコールバックへ引き渡す任意のポインタを指定します。

戻り値は `XmcStatus` です。成功時は `XMC_OK` が返ります。

xmc::RepeatingTimer::cancel
--------------------------------------------------------------------------------

.. code-block:: cpp

	void xmc::RepeatingTimer::cancel();

動作中タイマーを停止します。

タイマーが動作していない場合に呼び出しても問題ありません。

時刻取得
================================================================================

xmc::getTimeMs
--------------------------------------------------------------------------------

.. code-block:: cpp

	uint64_t xmc::getTimeMs();

システムが起動してからの経過時間をミリ秒単位で返します。

xmc::getTimeUs
--------------------------------------------------------------------------------

.. code-block:: cpp

	uint64_t xmc::getTimeUs();

システムが起動してからの経過時間をマイクロ秒単位で返します。

待機
================================================================================

xmc::sleepMs
--------------------------------------------------------------------------------

.. code-block:: cpp

	void xmc::sleepMs(uint32_t ms);

指定ミリ秒だけスリープします。

`ms` には待機時間をミリ秒単位で指定します。

xmc::sleepUs
--------------------------------------------------------------------------------

.. code-block:: cpp

	void xmc::sleepUs(uint32_t us);

指定マイクロ秒だけスリープします。

`us` には待機時間をマイクロ秒単位で指定します。

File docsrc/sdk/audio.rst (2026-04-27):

オーディオ API
################################################################################

グローバル関数
================================================================================

xmc::audio::setMuted
--------------------------------------------------------------------------------

.. code-block:: cpp

  XmcStatus xmc::audio::setMuted(bool muted);

スピーカーのミュート状態を設定します。
この関数は IO エキスパンダを経由してパワーアンプのミュート端子を制御します。
true を指定するとスピーカーがミュートされ、false を指定するとミュートが解除されます。

処理が成功すると XMC_OK が返されます。処理に失敗した場合は、エラーコードが返されます。

xmc::audio::setSourcePort
--------------------------------------------------------------------------------

.. code-block:: cpp

  XmcStatus xmc::audio::setSourcePort(xmc::audio::SourcePort *src);

オーディオストリームのソースを指定します。通常は xmc::audio::Mixer クラスから取得したオーディオソースを指定します。

Mixer クラス
================================================================================

xmc::audio::Mixer クラスは、複数のオーディオソースをミックスして単一のオーディオストリームを生成するためのクラスです。

xmc::audio::createMixer
--------------------------------------------------------------------------------

.. code-block:: cpp

  xmc::audio::Mixer xmc::audio::createMixer(int numSources);

Mixer クラスのインスタンスを作成します。引数にはミックスするオーディオソースの数を指定します。

xmc::audio::Mixer::setSource
--------------------------------------------------------------------------------

.. code-block:: cpp

  void xmc::audio::Mixer::setSource(int index, xmc::audio::SourcePort *source)

ミックスするオーディオソースを指定します。index 引数は 0 から numSources-1 の範囲で、source 引数にはオーディオソースを指定します。

xmc::audio::Mixer::getOutputPort
--------------------------------------------------------------------------------

.. code-block:: cpp

  xmc::audio::SourcePort *xmc::audio::Mixer::getOutputPort()

ミックスされたオーディオストリームの出力ポートを取得します。
この出力ポートを xmc::audio::setSourcePort() 関数に渡すことで、ミックスされたオーディオをスピーカーに送ることができます。

Toneクラス
================================================================================

xmc::audio::Tone クラスは、シンプルなトーンジェネレータを実装したクラスです。
簡単な効果音の生成に使用できます。

xmc::audio::createTone
--------------------------------------------------------------------------------

.. code-block:: cpp

  xmc::audio::Tone xmc::audio::createTone();

Tone クラスのインスタンスを作成します。引数はありません。

xmc::audio::Tone::init
--------------------------------------------------------------------------------

.. code-block:: cpp

  void xmc::audio::Tone::init(uint32_t rateHz = 0)

トーンジェネレータを初期化します。引数にはサンプルレートを指定します。
0 を指定した場合は、スピーカーのサンプルレートが使用されます。

xmc::audio::Waveform
--------------------------------------------------------------------------------

Tone で使用する波形を表す列挙型です。

.. csv-table:: xmc::audio::Waveform の値
   :header: "値", "説明"

   "xmc::audio::Waveform::SQUARE", "矩形波"
   "xmc::audio::Waveform::SINE", "正弦波"
   "xmc::audio::Waveform::TRIANGLE", "三角波"
   "xmc::audio::Waveform::SAWTOOTH", "のこぎり波"
   "xmc::audio::Waveform::NOISE", "ノイズ"

xmc::audio::TONE_LENGTH_INFINITE
--------------------------------------------------------------------------------

.. code-block:: cpp

  static constexpr uint32_t xmc::audio::TONE_LENGTH_INFINITE = 0xFFFFFFFF;

音の再生長を「無限」にするための定数です。
`noteOn()` / `noteOnWithFreq()` の `lenMs` 引数に指定すると、`noteOff()` または `mute()` が呼ばれるまで再生を継続します。

xmc::audio::Tone::setWaveform
--------------------------------------------------------------------------------

.. code-block:: cpp

  void xmc::audio::Tone::setWaveform(xmc::audio::Waveform wf);

出力波形を設定します。

xmc::audio::Tone::getWaveform
--------------------------------------------------------------------------------

.. code-block:: cpp

  xmc::audio::Waveform xmc::audio::Tone::getWaveform() const;

現在設定されている出力波形を取得します。

xmc::audio::Tone::setVelocity
--------------------------------------------------------------------------------

.. code-block:: cpp

  void xmc::audio::Tone::setVelocity(uint8_t velo);

ベロシティ (音量) を設定します。値域は 0 から 127 です。
範囲外の値を指定した場合は、この範囲にクリップされます。

xmc::audio::Tone::getVelocity
--------------------------------------------------------------------------------

.. code-block:: cpp

  uint8_t xmc::audio::Tone::getVelocity() const;

現在のベロシティを取得します。

xmc::audio::Tone::setEnvelope
--------------------------------------------------------------------------------

.. code-block:: cpp

  void xmc::audio::Tone::setEnvelope(uint16_t attackMs, uint16_t decayMs, uint16_t sustainLevel, uint16_t releaseMs);

ADSR エンベロープを設定します。

- `attackMs`: アタック時間 [ms]
- `decayMs`: ディケイ時間 [ms]
- `sustainLevel`: サステインレベル (0 から 256)
- `releaseMs`: リリース時間 [ms]

xmc::audio::Tone::setSweep
--------------------------------------------------------------------------------

.. code-block:: cpp

  void xmc::audio::Tone::setSweep(int32_t delta, uint32_t periodMs);

ピッチスイープを設定します。
`periodMs` ごとに現在の周波数に対して係数を乗算し、徐々に音程を変化させます。

`delta` は 16 ビット小数部を持つ固定小数点値として扱われます。
有効範囲は -32768 から 65536 で、内部ではこの範囲にクリップされます。
`delta = 0` の場合はスイープ係数が 1.0 となり、ピッチは変化しません。

xmc::audio::Tone::noteOn
--------------------------------------------------------------------------------

.. code-block:: cpp

  void xmc::audio::Tone::noteOn(uint8_t note, uint32_t lenMs = xmc::audio::TONE_LENGTH_INFINITE);

MIDI ノート番号を指定して再生を開始します。
`note` は 0 から 127 で、69 は A4 (440 Hz) に対応します。

`lenMs` で再生長 [ms] を指定します。
`xmc::audio::TONE_LENGTH_INFINITE` を指定した場合、明示的に停止するまで再生を継続します。

xmc::audio::Tone::noteOnWithFreq
--------------------------------------------------------------------------------

.. code-block:: cpp

  void xmc::audio::Tone::noteOnWithFreq(uint32_t freq, uint32_t lenMs = xmc::audio::TONE_LENGTH_INFINITE);

周波数 [Hz] を直接指定して再生を開始します。
`freq` に 0 を指定した場合は再生を停止します。

xmc::audio::Tone::noteOff
--------------------------------------------------------------------------------

.. code-block:: cpp

  void xmc::audio::Tone::noteOff();

現在のノートを停止します。
`releaseMs` が 0 より大きい場合はリリースフェーズへ遷移し、0 の場合は即座に停止します。

xmc::audio::Tone::mute
--------------------------------------------------------------------------------

.. code-block:: cpp

  void xmc::audio::Tone::mute();

音を即座にミュートします。エンベロープのリリースフェーズは経由しません。

xmc::audio::Tone::render
--------------------------------------------------------------------------------

.. code-block:: cpp

  void xmc::audio::Tone::render(int16_t *buffer, uint32_t numSamples);

指定したバッファに PCM サンプルを加算生成します。
通常はオーディオシステム内部から呼ばれる関数で、アプリケーションコードから直接呼ぶ必要はありません。

xmc::audio::Tone::getOutputPort
--------------------------------------------------------------------------------

.. code-block:: cpp

  xmc::audio::SourcePort *xmc::audio::Tone::getOutputPort();

Tone の出力ポートを取得します。
取得したポートは `xmc::audio::Mixer::setSource()` や `xmc::audio::setSourcePort()` に渡して利用できます。

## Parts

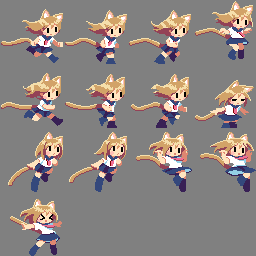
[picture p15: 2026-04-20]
cpp/example/shapo_jump/material/bmp_shapo.png

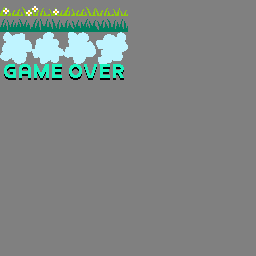
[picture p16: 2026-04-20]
cpp/example/shapo_jump/material/bmp_bg.png

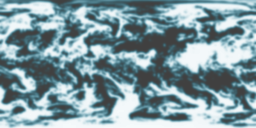
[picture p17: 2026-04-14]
material/texture/earth_cloud.png

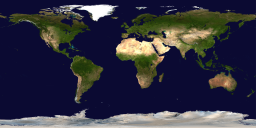
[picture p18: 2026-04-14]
material/texture/earth_surface.png

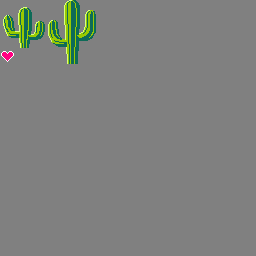
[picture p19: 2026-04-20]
cpp/example/shapo_jump/material/bmp_chara.png

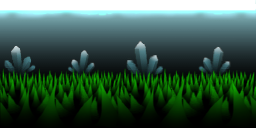
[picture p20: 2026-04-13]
material/texture/cave_env_texture.png

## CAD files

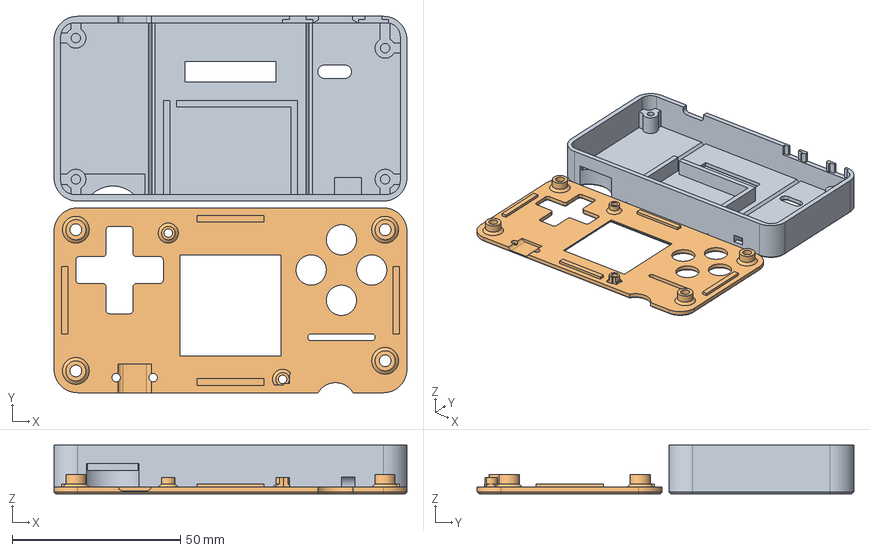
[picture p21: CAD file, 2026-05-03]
enclosure/full/full_body.step
105.0 x 112.0 x 14.5 mm

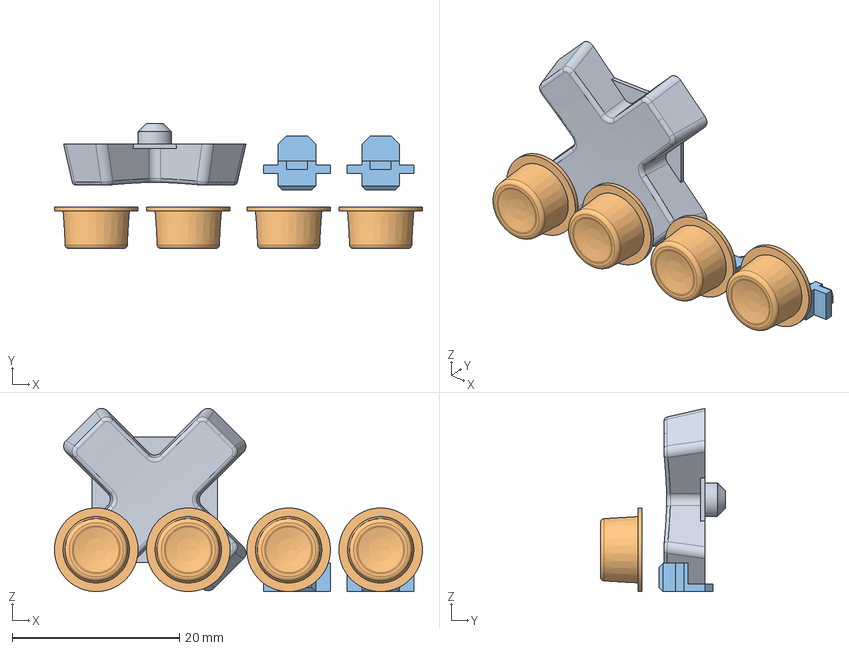
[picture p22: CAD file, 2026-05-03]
enclosure/full/full_keys.step
44.0 x 15.0 x 21.9 mm

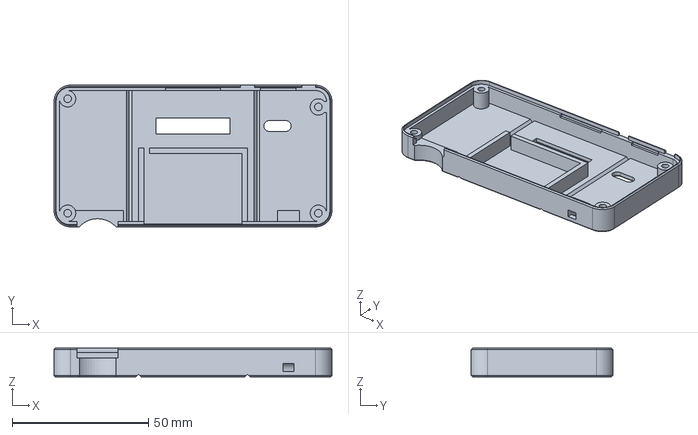
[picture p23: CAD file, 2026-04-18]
enclosure/simple/simple.step
102.0 x 52.0 x 10.6 mm

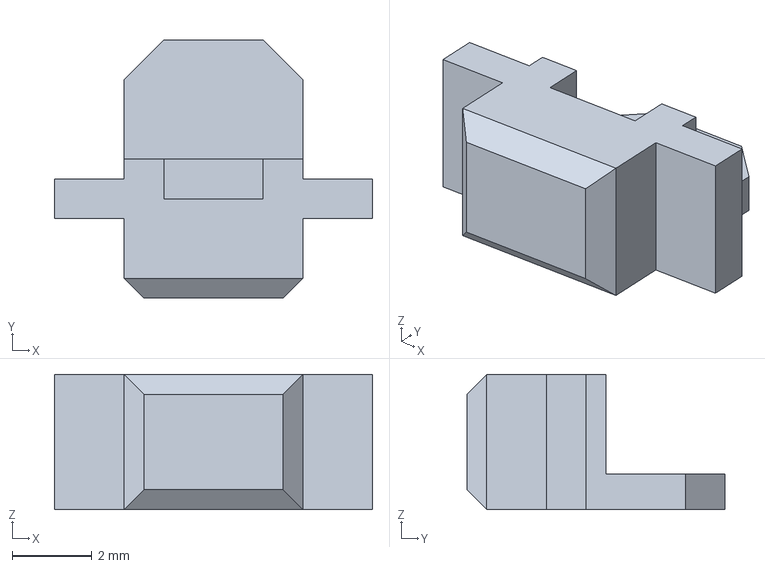
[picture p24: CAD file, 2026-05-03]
enclosure/full/top_key.step
8.00 x 6.50 x 3.40 mm

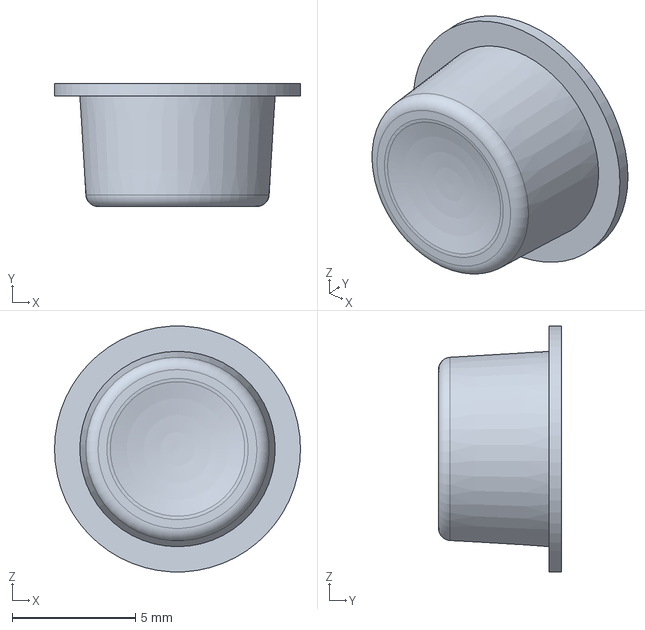
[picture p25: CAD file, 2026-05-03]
enclosure/full/abxy_key.step
10.0 x 5.00 x 9.99 mm

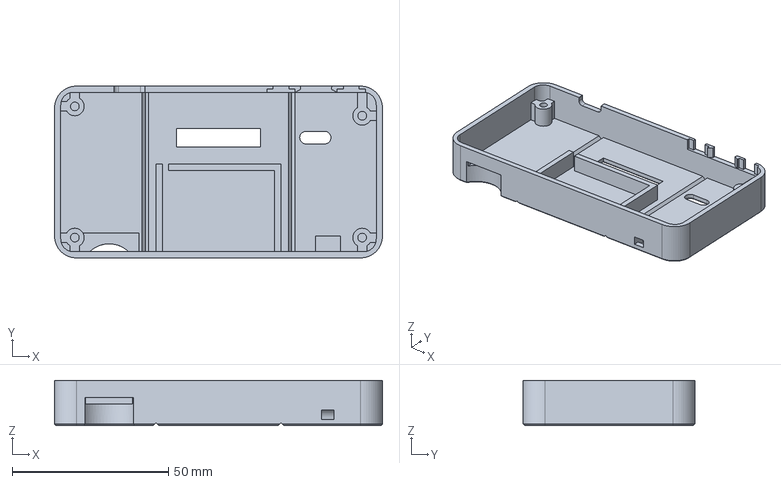
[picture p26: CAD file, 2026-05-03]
enclosure/full/back.step
105.0 x 55.0 x 14.5 mm

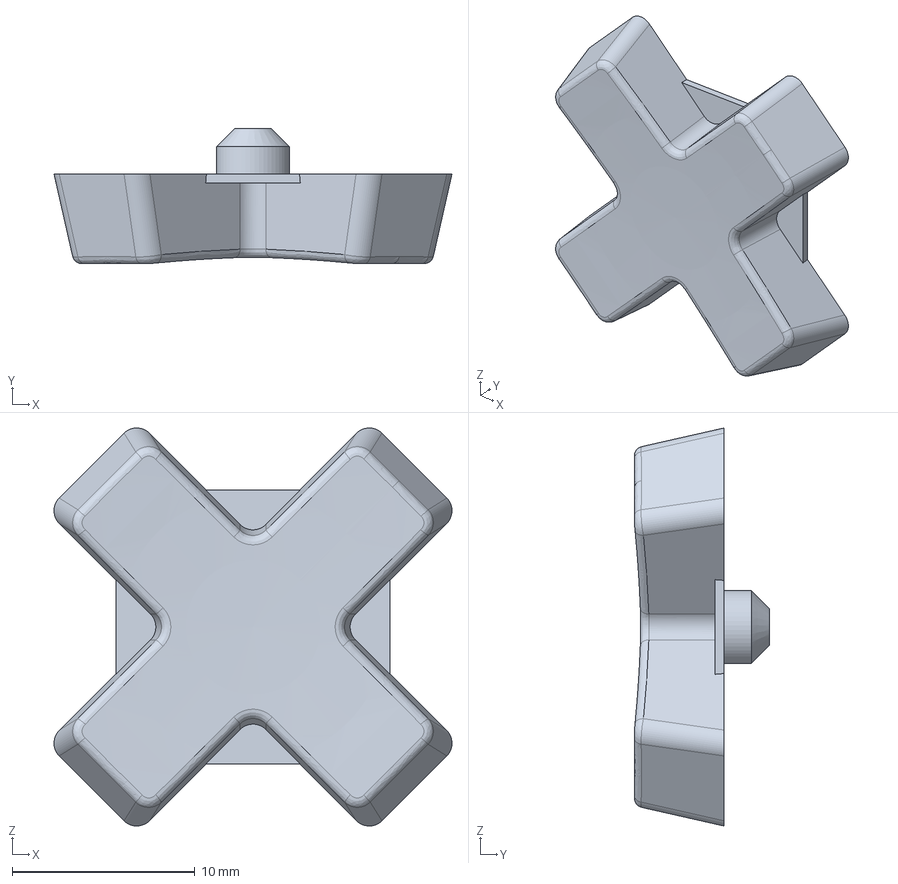
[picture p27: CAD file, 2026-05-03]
enclosure/full/dpad_key.step
21.8 x 7.41 x 21.8 mm

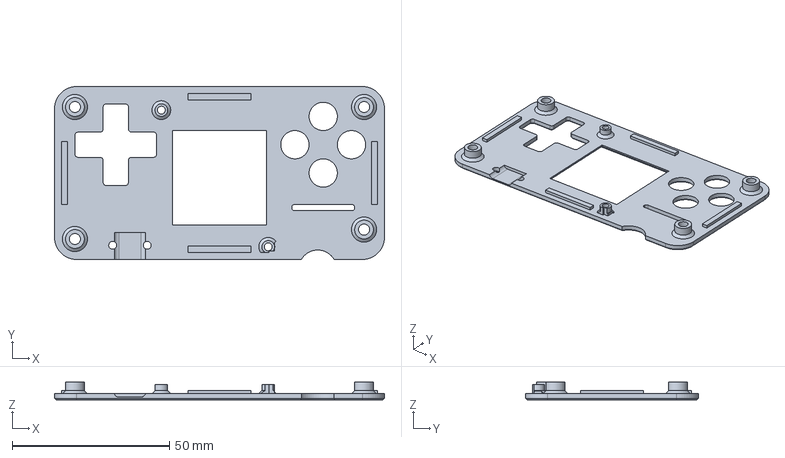
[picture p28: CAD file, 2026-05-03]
enclosure/full/front.step
105.0 x 55.0 x 5.70 mm

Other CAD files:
enclosure/full/abxy_key.stl
enclosure/full/back.stl
enclosure/full/dpad_key.stl
enclosure/full/front.stl
enclosure/full/full_body.stl
enclosure/full/full_keys.stl
enclosure/full/top_key.stl
enclosure/simple/simple.stl

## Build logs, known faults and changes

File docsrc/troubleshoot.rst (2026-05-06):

トラブルシューティング
################################################################################

ESP32S3 版で、アプリを書き込むと再起動を繰り返す
================================================================================

ファンクションキーを押しながら電源ボタンを長押し (リセット) すると
Xiamocon はアプリを起動する前にセーフモードに入ろうとします。
セーフモードでの起動が成功すれば、その状態でアプリを書き換えたり
電源ボタンで電源を切ることができます。

セーフモードでも再起動を繰り返す場合は、XIAO 本体基板の BOOT ボタンを押しながら
電源ボタンを長押し (リセット) してブートローダーを起動し、
再起動が発生しない正常なアプリを書き込んでください。

アプリが再起動を繰り返す原因は、アプリやライブラリのバグの場合もあればメモリ不足の場合もあります。
メモリ不足については「メモリ不足対策」の項を参照してください。

セーフモードでも再起動を繰り返す場合、静的に宣言された配列のための領域確保に失敗している可能性が濃厚です。
メモリの確保は new 演算子、malloc、または xmcMalloc 関数を使用して動的に行うことを推奨します。

メモリ不足対策
================================================================================

RP2350 版では 520kB の SRAM しか搭載していないので、そもそもその範囲内の使用に収める必要があります。

ESP32S3 版は 512kB の SRAM の他に 8MB の PSRAM を搭載していますが、
PSRAM を有効に活用するためには適切な方法でメモリ確保を実施する必要があります。

フレームバッファが使用するメモリを節約する
--------------------------------------------------------------------------------

PSRAM は DMA に使用できないため、FrameBuffer クラスはバッファ領域を SRAM に確保します。
DMA で使用するため、このバッファ領域は物理的に連続していなければなりません。
RGB565 形式でダブルバッファを有効にすると、112.5kB の連続した領域が 2 つ確保されます。
これがどのように SRAM 上に配置されるかによっては、SRAM の空き空間が断片化され、
他の大きな配列領域などを SRAM 上に確保しようとして失敗する可能性があります。
これは Xiamocon が再起動を繰り返して制御不能になる主要な原因の一つです。

グラフィックスのパフォーマンスは低下しますが、ピクセルフォーマットを RGB444 にするか、
ダブルバッファを無効にすることでこの問題を回避しやすくなります。

フレームバッファ以外のメモリを PSRAM に確保する (ESP32S3 版)
--------------------------------------------------------------------------------

大きな配列を静的に宣言したり new 演算子で確保する場合、領域がどこに確保されるかを制御できません。

.. code-block:: cpp

	int32_t largeArray1[1024];

xmcMalloc 関数を使用すると、領域を SRAM と PSRAM のどちらに確保するかを指定できます。
ESP32S3 版では、第二引数に XMC_HEAP_CAP_SPIRAM を指定すると PSRAM に確保されます。

.. code-block:: cpp

	int32_t *largeArray2 = (int32_t *)xmcMalloc(1024 * sizeof(int32_t), XMC_HEAP_CAP_SPIRAM);

RP3250 版では第二引数は無視され、常に SRAM に確保されます。

静的なデータをできるだけ Flash ROM に配置する
--------------------------------------------------------------------------------

実行中に内容が変化しない静的なデータは const 修飾子を付けて宣言することで、Flash ROM に配置されます。

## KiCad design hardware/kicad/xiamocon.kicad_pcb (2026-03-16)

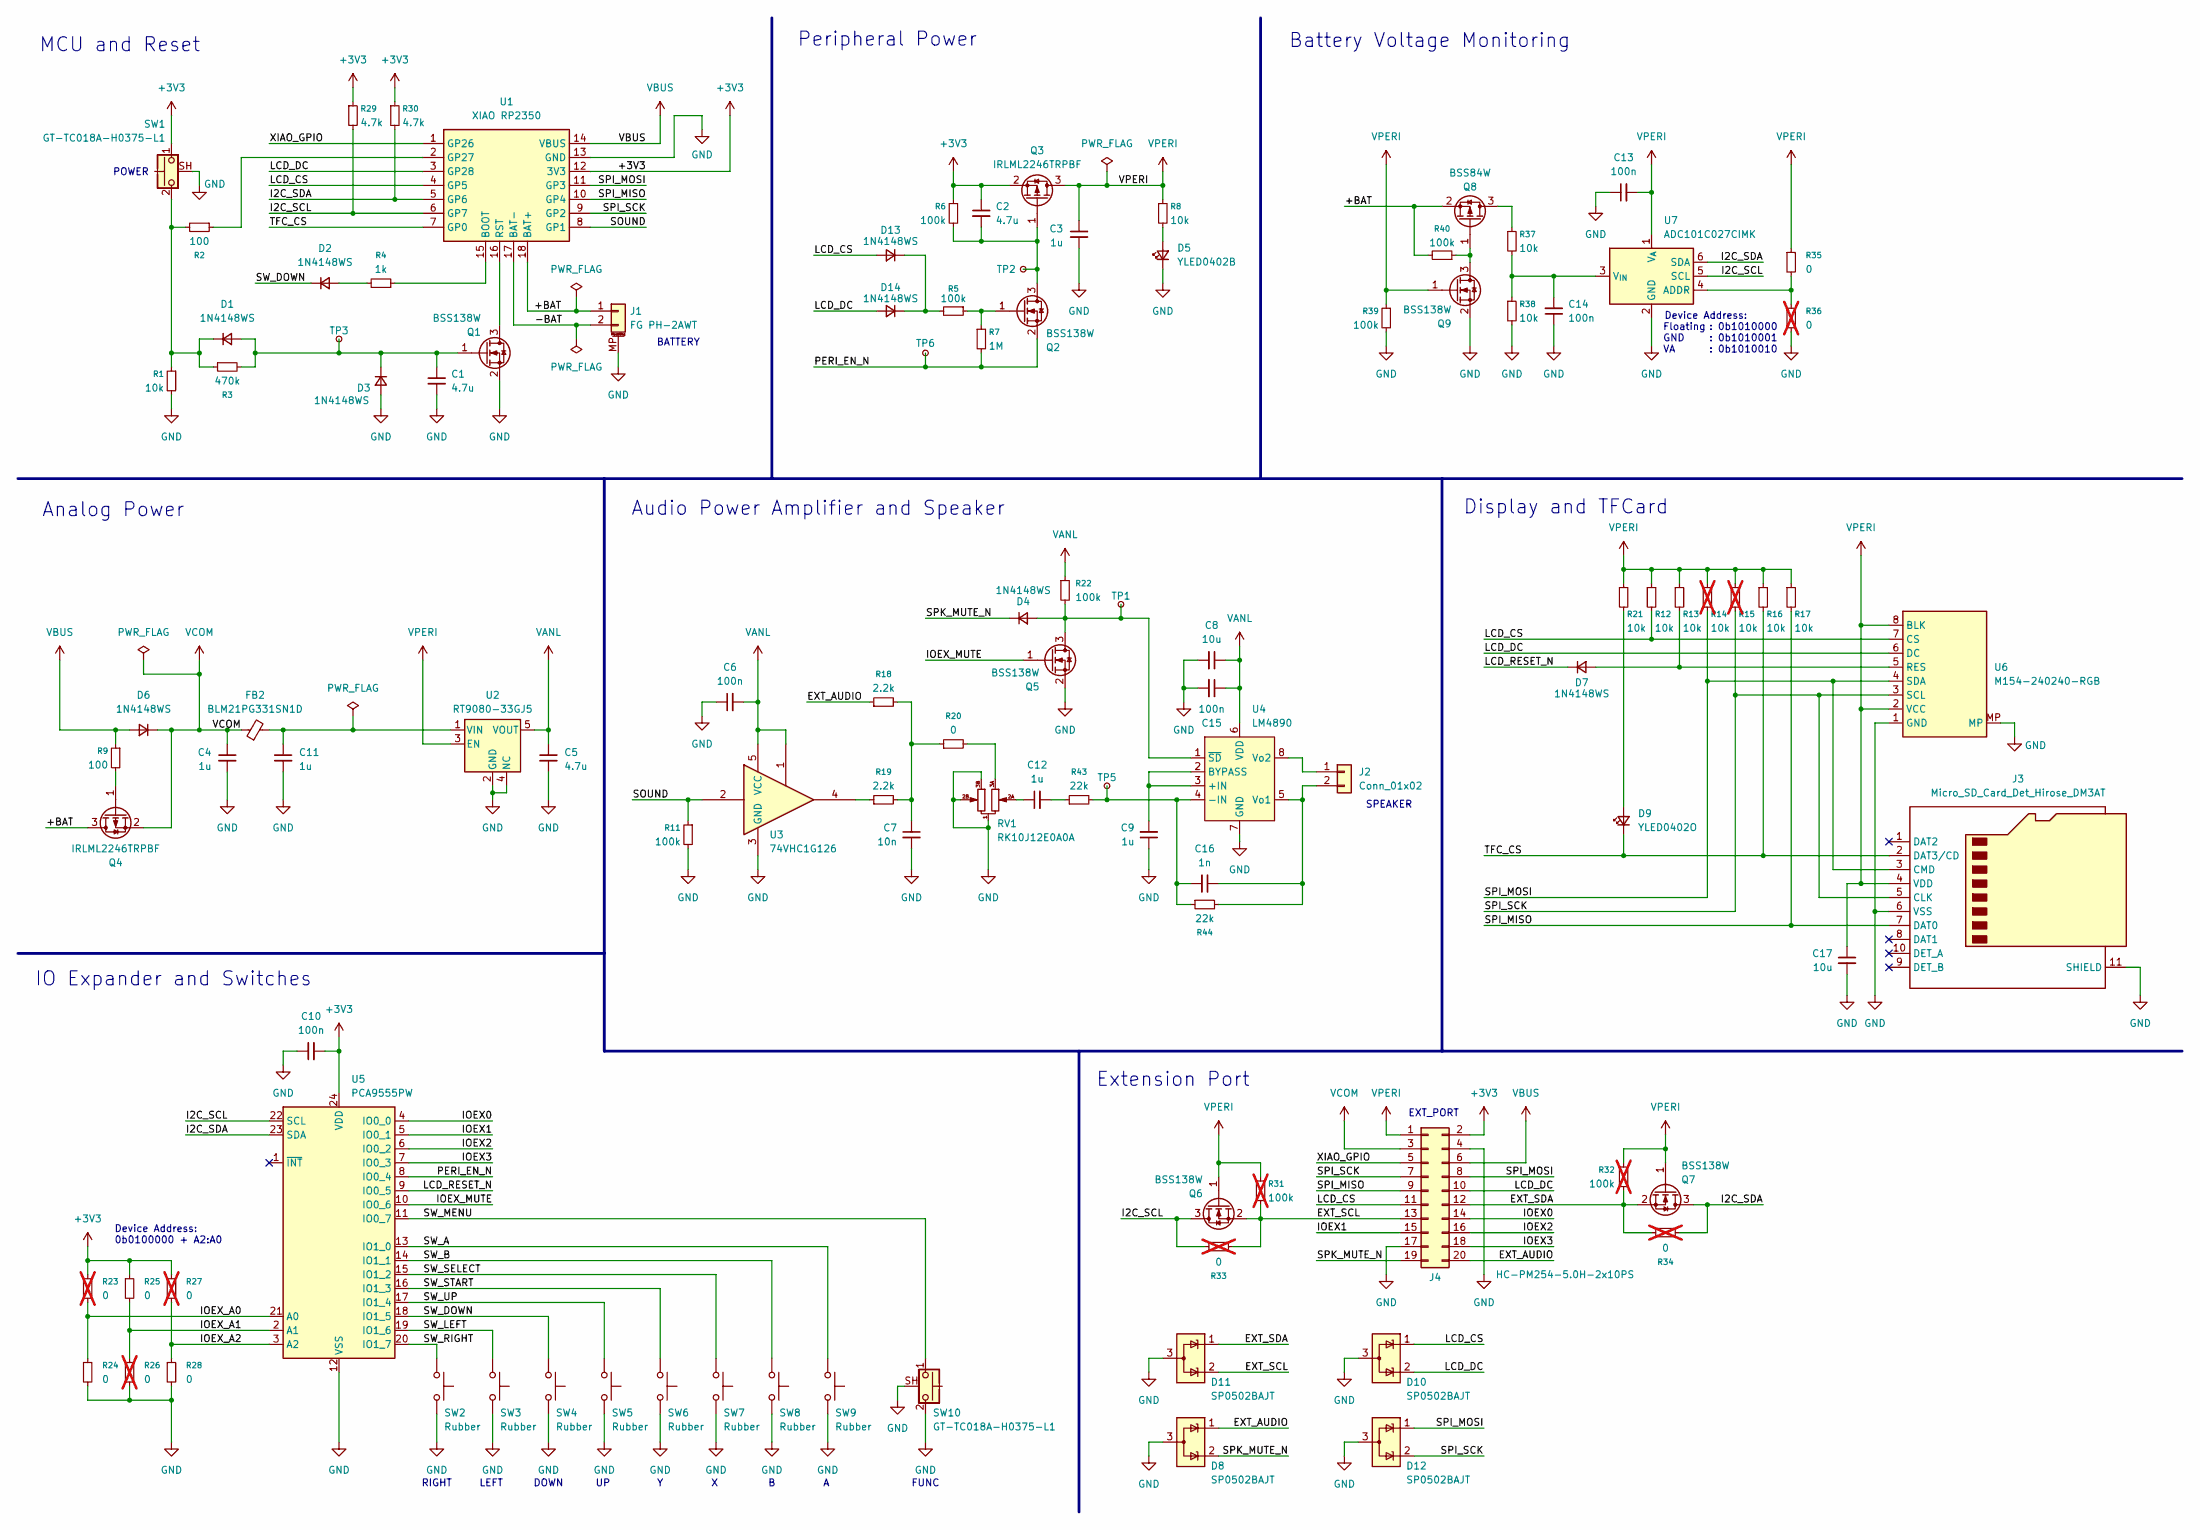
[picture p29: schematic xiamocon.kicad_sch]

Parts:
C1, C2, C5: 4.7u; C_0603_1608Metric; LCSC C1705
C3, C4, C11: 1u; C_0402_1005Metric; LCSC C14445
C6, C10, C13, C14, C15: 100n; C_0402_1005Metric; LCSC C1525
C7: 10n; C_0402_1005Metric; LCSC C15195
C8, C17: 10u; C_0603_1608Metric; LCSC C1691
C9, C12: 1u; C_0603_1608Metric; LCSC C140782
C16: 1n; C_0402_1005Metric; LCSC C14442
D1, D2, D3, D4, D7, D13, D14: 1N4148WS; D_SOD-523; LCSC C917006
D5: YLED0402B; LED_0402_1005Metric_Pad0.77x0.64mm_HandSolder; LCSC C30584803
D6: 1N4148WS; D_SOD-323; LCSC C60580
D8, D10, D11, D12: SP0502BAJT; SOT-323_SC-70; LCSC C207262
D9: YLED0402O; LED_0402_1005Metric_Pad0.77x0.64mm_HandSolder; LCSC C28310436
FB2: BLM21PG331SN1D; L_0805_2012Metric; LCSC C74764
J1: FG PH-2AWT; JST_PH_S2B-PH-SM4-TB_1x02-1MP_P2.00mm_Horizontal; LCSC C2763693
J2: Conn_01x02; SolderWirePad_1x02_SMD_150x50mil
J3: Micro_SD_Card_Det_Hirose_DM3AT; microSD_HC_Hirose_DM3AT-SF-PEJM5; LCSC C114218
J4: HC-PM254-5.0H-2x10PS; PinSocket_2x10_P2.54mm_Vertical_SMD; LCSC C42163138
Q1, Q2, Q5, Q6, Q7, Q9: BSS138W; SOT-323_SC-70; LCSC C504052
Q3, Q4: IRLML2246TRPBF; SOT-23; LCSC C127272
Q8: BSS84W; SOT-323_SC-70; LCSC C919394
R1, R12, R13, R16, R17, R37, R38: 10k; R_0402_1005Metric; LCSC C60490
R2, R9: 100; R_0402_1005Metric; LCSC C106232
R3: 470k; R_0402_1005Metric; LCSC C137976
R4: 1k; R_0402_1005Metric; LCSC C106235
R5, R6, R11, R22, R39, R40: 100k; R_0402_1005Metric; LCSC C60491
R7: 1M; R_0402_1005Metric; LCSC C138033
R8, R21: 10k; R_0402_1005Metric_Pad0.72x0.64mm_HandSolder; LCSC C60490
R14, R15: 10k; R_0402_1005Metric; LCSC C60490; not fitted
R18, R19: 2.2k; R_0402_1005Metric; LCSC C114762
R20, R24, R25, R28, R35: 0; R_0402_1005Metric; LCSC C106231
R23, R26, R27, R33, R34, R36: 0; R_0402_1005Metric; LCSC C106231; not fitted
R29, R30: 4.7k; R_0402_1005Metric; LCSC C105871
R31, R32: 100k; R_0402_1005Metric; LCSC C60491; not fitted
R43, R44: 22k; R_0402_1005Metric; LCSC C82868
RV1: RK10J12E0A0A; RK10J1xE; LCSC C351176
SW1, SW10: GT-TC018A-H0375-L1; LCSC C963235
SW2, SW3, SW4, SW5, SW6, SW7, SW8, SW9: Rubber; Rubber_Contact
TP1, TP2, TP3, TP5, TP6: PWAMP_CE; TestPoint_Pad_D1.5mm
U1: XIAO RP2350
U2: RT9080-33GJ5; TSOT-23-5; LCSC C841192
U3: 74VHC1G126; SOT-23-5; LCSC C53100485
U4: LM4890; MSOP-8_3x3mm_P0.65mm; LCSC C329452
U5: PCA9555PW; TSSOP-24_4.4x7.8mm_P0.65mm; LCSC C128392
U6: M154-240240-RGB
U7: ADC101C027CIMK; TSOT-23-6; LCSC C701590

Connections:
+3V3: C2.1, C10.2, J4.2, Q3.2 (S), R6.1, R23.1, R25.1, R27.1, R29.1, R30.1, SW1.1, U1.12 (3V3), U5.24 (VDD)
/+BAT: J1.1, Q4.3 (D), Q8.2 (S), R40.2, U1.18 (BAT+)
/-BAT: J1.2, U1.17 (BAT-)
/EXT_AUDIO: D8.1 (K), J4.20, R18.1
/EXT_SCL: D11.2 (K), J4.13, Q6.2 (S), R31.2, R33.2
/EXT_SDA: D11.1 (K), J4.12, Q7.2 (S), R32.2, R34.1
/I2C_SCL: Q6.3 (D), R29.2, R33.1, U1.6 (GP7), U5.22 (SCL), U7.5 (SCL)
/I2C_SDA: Q7.3 (D), R30.2, R34.2, U1.5 (GP6), U5.23 (SDA), U7.6 (SDA)
/IOEX0: J4.14, U5.4 (IO0_0)
/IOEX1: J4.15, U5.5 (IO0_1)
/IOEX2: J4.16, U5.6 (IO0_2)
/IOEX3: J4.18, U5.7 (IO0_3)
/IOEX_A0: R23.2, R24.1, U5.21 (A0)
/IOEX_A1: R25.2, R26.1, U5.2 (A1)
/IOEX_A2: R27.2, R28.1, U5.3 (A2)
/IOEX_MUTE: Q5.1 (G), U5.10 (IO0_6)
/LCD_CS: D10.1 (K), D13.2 (A), J4.11, R12.2, U1.4 (GP5), U6.7 (CS)
/LCD_DC: D10.2 (K), D14.2 (A), J4.10, U1.3 (GP28), U6.6 (DC)
/LCD_RESET_N: D7.1 (K), U5.9 (IO0_5)
/PERI_EN_N: Q2.2 (S), R7.2, TP6.1, U5.8 (IO0_4)
/SOUND: R11.1, U1.8 (GP1), U3.2
/SPI_MISO: J3.7 (DAT0), J4.9, R17.2, U1.10 (GP4)
/SPI_MOSI: D12.1 (K), J3.3 (CMD), J4.8, R14.2, U1.11 (GP3), U6.4 (SDA)
/SPI_SCK: D12.2 (K), J3.5 (CLK), J4.7, R15.2, U1.9 (GP2), U6.3 (SCL)
/SPK_MUTE_N: D4.1 (K), D8.2 (K), J4.19
/SW_A: SW9.1, U5.13 (IO1_0)
/SW_B: SW8.1, U5.14 (IO1_1)
/SW_DOWN: D2.1 (K), SW4.1, U5.18 (IO1_5)
/SW_LEFT: SW3.1, U5.19 (IO1_6)
/SW_MENU: SW10.1, U5.11 (IO0_7)
/SW_RIGHT: SW2.1, U5.20 (IO1_7)
/SW_SELECT: SW7.1, U5.15 (IO1_2)
/SW_START: SW6.1, U5.16 (IO1_3)
/SW_UP: SW5.1, U5.17 (IO1_4)
/TFC_CS: D9.1 (K), J3.2 (DAT3/CD), R16.2, U1.7 (GP0)
/XIAO_GPIO: J4.5, U1.1 (GP26)
GND: C1.2, C3.2, C4.2, C5.2, C6.1, C7.2, C8.2, C9.1, C10.1, C11.2, C13.1, C14.1, C15.2, C17.2, D3.2 (A), D5.1 (K), D8.3 (A), D10.3 (A), D11.3 (A), D12.3 (A), J1.MP (MountPin), J3.6 (VSS), J3.11 (SHIELD), J4.4, J4.17, Q1.2 (S), Q5.2 (S), Q9.2 (S), R1.2, R11.2, R24.2, R26.2, R28.2, R36.2, R38.2, R39.2, RV1.1, RV1.2B, RV1.3B, SW1.SH (B), SW2.2, SW3.2, SW4.2, SW5.2, SW6.2, SW7.2, SW8.2, SW9.2, SW10.2, SW10.SH (B), U1.13 (GND), U2.2 (GND), U2.4 (NC), U3.3 (GND), U4.7 (GND), U5.12 (VSS), U6.1 (GND), U6.MP, U7.2 (GND)
unnamed: C7.1, R18.2, R19.2, R20.1
unnamed: C12.1, RV1.2A
unnamed: C12.2, R43.1
unnamed: C1.1, D1.2 (A), D3.1 (K), Q1.1 (G), R3.2, TP3.1
unnamed: D1.1 (K), R1.1, R2.2, R3.1, SW1.2
unnamed: D2.2 (A), R4.2
unnamed: D4.2 (A), Q5.3 (D), R22.2, TP1.1, U4.1 (~SD)
unnamed: D5.2 (A), R8.2
unnamed: D7.2 (A), R13.2, U6.5 (RES)
unnamed: D9.2 (A), R21.2
unnamed: D13.1 (K), D14.1 (K), R5.2
unnamed: J2.1, U4.8 (Vo2)
unnamed: C16.1, J2.2, R44.2, U4.5 (Vo1)
unnamed: Q1.3 (D), U1.16 (RST)
unnamed: C2.2, Q2.3 (D), Q3.1 (G), R6.2, TP2.1
unnamed: Q2.1 (G), R5.1, R7.1
unnamed: Q4.1 (G), R9.2
unnamed: Q8.3 (D), R37.1
unnamed: Q8.1 (G), Q9.3 (D), R40.1
unnamed: R19.1, U3.4
unnamed: R20.2, RV1.3A
unnamed: R4.1, U1.15 (BOOT)
unnamed: R2.1, U1.2 (GP27)
unnamed: C11.1, FB2.2, U2.1 (VIN)
unnamed: C9.2, U4.2 (BYPASS), U4.3 (+IN)
unnamed: C16.2, R43.2, R44.1, TP5.1, U4.4 (-IN)
unnamed: R35.2, R36.1, U7.4 (ADDR)
unnamed: C14.2, R37.2, R38.1, U7.3 (V_{IN})
VANL: C5.1, C6.2, C8.1, C15.1, R22.1, U2.5 (VOUT), U3.1, U3.5 (VCC), U4.6 (VDD)
VBUS: D6.2 (A), J4.6, R9.1, U1.14 (VBUS)
VCOM: C4.1, D6.1 (K), FB2.1, J4.3, Q4.2 (S)
VPERI: C3.1, C13.2, C17.1, J3.4 (VDD), J4.1, Q3.3 (D), Q6.1 (G), Q7.1 (G), Q9.1 (G), R8.1, R12.1, R13.1, R14.1, R15.1, R16.1, R17.1, R21.1, R31.1, R32.1, R35.1, R39.1, U2.3 (EN), U6.2 (VCC), U6.8 (BLK), U7.1 (V_{A})

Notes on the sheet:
LEFT
BATTERY
Display and TFCard
Audio Power Amplifier and Speaker
DOWN
Device Address:
Extension Port
RIGHT
Floating GND VA
SPEAKER
Peripheral Power
Device Address: 0b0100000 + A2:A0
Battery Voltage Monitoring
MCU and Reset
EXT_PORT
POWER
IO Expander and Switches
: 0b1010000 : 0b1010001 : 0b1010010
FUNC
Analog Power

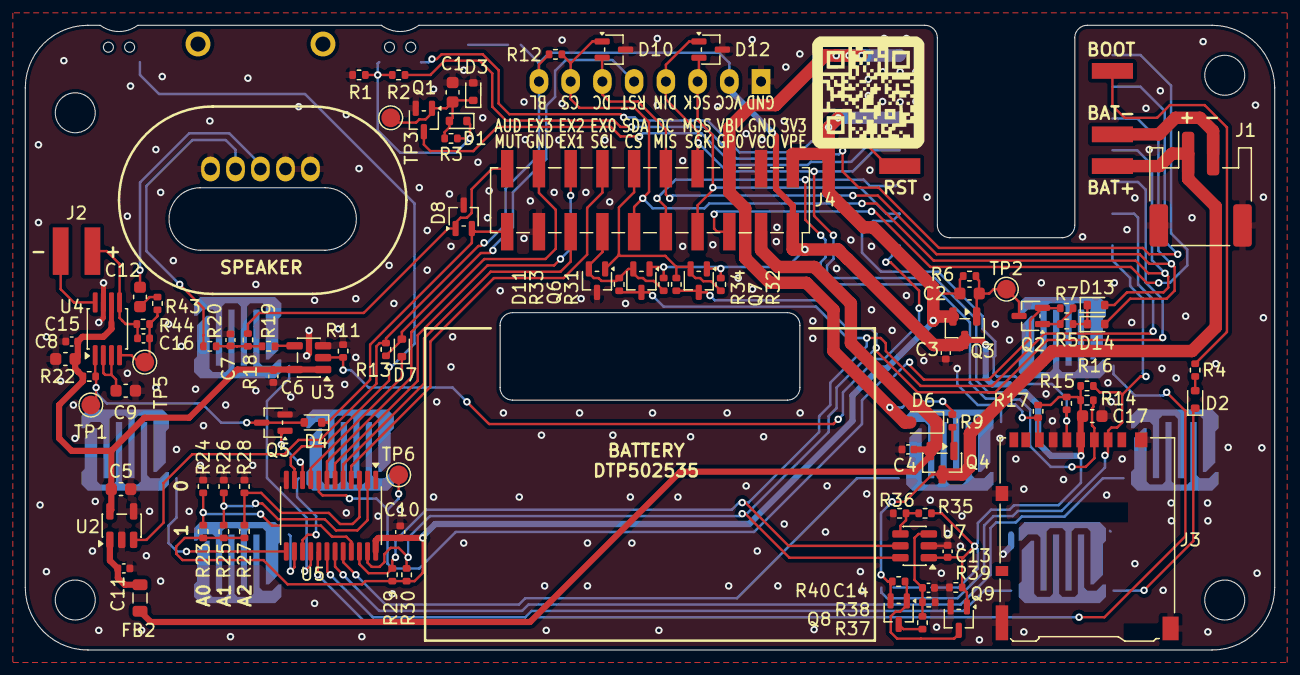
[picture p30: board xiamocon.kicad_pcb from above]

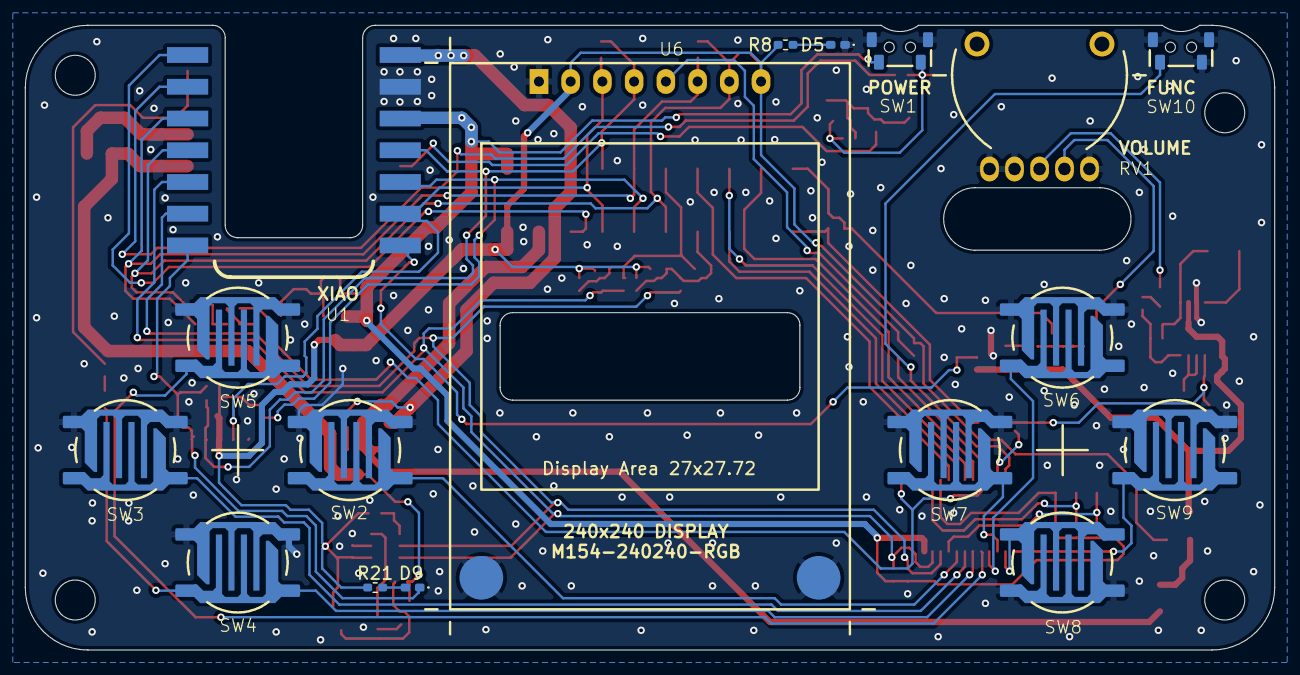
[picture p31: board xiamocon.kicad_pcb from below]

Board: 2 copper layers, 100.0 x 50.0 mm, 109 parts (17 on the bottom side), 69 nets.

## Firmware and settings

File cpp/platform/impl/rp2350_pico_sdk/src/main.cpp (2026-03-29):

#include "xmc/app_entry.hpp"

#include <hardware/clocks.h>
#include <hardware/vreg.h>
#include <pico/stdlib.h>

static const uint32_t SYS_CLK_FREQ = 250000000;

int main() {
#if 1
  vreg_set_voltage(VREG_VOLTAGE_1_30);
  sleep_ms(100);
  set_sys_clock_khz(SYS_CLK_FREQ / 1000, true);
  clock_configure(clk_peri, 0, CLOCKS_CLK_PERI_CTRL_AUXSRC_VALUE_CLKSRC_PLL_SYS,
                  SYS_CLK_FREQ, SYS_CLK_FREQ);
#endif
  xmc::libSetup();
  while (true) {
    xmc::libLoop();
  }
  return 0;
}

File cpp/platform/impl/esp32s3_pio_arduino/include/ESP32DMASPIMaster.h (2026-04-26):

// original version:
// https://github.com/hideakitai/ESP32DMASPI/blob/ab1587f92fdb1629f8a5fbc97fa6ad55a8bd6847/ESP32DMASPIMaster.h

// modified by Shapoco:
// - short transaction support
// - changed RECV_TRANS_QUEUE_TIMEOUT_TICKS from 5000 to 100
//   to allow for quick reinitialization on frequency changes.
// - ESP-IDF 5.5.x support

#pragma once
#ifndef ESP32DMASPI_MASTER_H
#define ESP32DMASPI_MASTER_H

#include <Arduino.h>
#include <SPI.h>
#include <driver/spi_master.h>
#include <esp_log.h>
#include <soc/soc_caps.h>
#include <vector>
#include <string>
#include <memory>

#ifndef ARDUINO_ESP32_DMA_SPI_NAMESPACE_BEGIN
#define ARDUINO_ESP32_DMA_SPI_NAMESPACE_BEGIN \
    namespace arduino {                       \
    namespace esp32 {                         \
        namespace spi {                       \
            namespace dma {
#endif
#ifndef ARDUINO_ESP32_DMA_SPI_NAMESPACE_END
#define ARDUINO_ESP32_DMA_SPI_NAMESPACE_END \
    }                                       \
    }                                       \
    }                                       \
    }
#endif

ARDUINO_ESP32_DMA_SPI_NAMESPACE_BEGIN

static constexpr const char *TAG = "ESP32DMASPIMaster";
static constexpr int SPI_MASTER_TASK_STASCK_SIZE = 1024 * 2;
static constexpr int SPI_MASTER_TASK_PRIORITY = 5;

static QueueHandle_t s_trans_queue_handle {NULL};
static constexpr int SEND_TRANS_QUEUE_TIMEOUT_TICKS = pdMS_TO_TICKS(5000);
static constexpr int RECV_TRANS_QUEUE_TIMEOUT_TICKS = pdMS_TO_TICKS(100);
static QueueHandle_t s_trans_result_handle {NULL};
static constexpr int SEND_TRANS_RESULT_TIMEOUT_TICKS = pdMS_TO_TICKS(5000);
static constexpr int RECV_TRANS_RESULT_TIMEOUT_TICKS = 0;
static QueueHandle_t s_trans_error_handle {NULL};
static constexpr int SEND_TRANS_ERROR_TIMEOUT_TICKS = pdMS_TO_TICKS(5000);
static constexpr int RECV_TRANS_ERROR_TIMEOUT_TICKS = 0;
static QueueHandle_t s_in_flight_mailbox_handle {NULL};

using spi_master_user_cb_t = std::function<void(spi_transaction_t*, void*)>;

void spi_master_pre_cb(spi_transaction_t* trans);
void spi_master_post_cb(spi_transaction_t* trans);
struct spi_master_context_t
{
    spi_device_interface_config_t if_cfg {
        .command_bits = 0,  // 0-16
        .address_bits = 0,  // 0-64
        .dummy_bits = 0,
        .mode = SPI_MODE0,
#if ESP_IDF_VERSION >= ESP_IDF_VERSION_VAL(5, 4, 1)
        .clock_source = SPI_CLK_SRC_DEFAULT,
#endif
        .duty_cycle_pos = 128,  // default: 128
        .cs_ena_pretrans = 0,   // only for half-duplex
        .cs_ena_posttrans = 0,
        .clock_speed_hz = SPI_MASTER_FREQ_8M,
        .input_delay_ns = 0,
#if ESP_IDF_VERSION >= ESP_IDF_VERSION_VAL(5, 4, 1)
        .sample_point = SPI_SAMPLING_POINT_PHASE_0,
#endif
        .spics_io_num = SS,
        .flags = 0,
        .queue_size = 1,
        .pre_cb = spi_master_pre_cb,
        .post_cb = spi_master_post_cb,
    };
    spi_bus_config_t bus_cfg {
        .mosi_io_num = MOSI, // union with data0_io_num
        .miso_io_num = MISO, // union with data1_io_num
        .sclk_io_num = SCK,
        .data2_io_num = -1,  // union with quadwp_io_num
        .data3_io_num = -1,  // union with quadhd_io_num
        .data4_io_num = -1,
        .data5_io_num = -1,
        .data6_io_num = -1,
        .data7_io_num = -1,
#if ESP_IDF_VERSION >= ESP_IDF_VERSION_VAL(5, 4, 1)
        .data_io_default_level = false,
#endif
        .max_transfer_sz = 4092,  // default: 4092 if DMA enabled, SOC_SPI_MAXIMUM_BUFFER_SIZE if DMA disabled
        .flags = SPICOMMON_BUSFLAG_MASTER,
#if ESP_IDF_VERSION >= ESP_IDF_VERSION_VAL(5, 2, 0)
        .isr_cpu_id = ESP_INTR_CPU_AFFINITY_AUTO,
#elif ESP_IDF_VERSION >= ESP_IDF_VERSION_VAL(5, 1, 0)
        .isr_cpu_id = INTR_CPU_ID_AUTO,
#endif
        .intr_flags = 0,
    };
    spi_host_device_t host {SPI2_HOST};
    int dma_chan {SPI_DMA_CH_AUTO};  // must be 1, 2 or AUTO
    TaskHandle_t main_task_handle {NULL};
};

struct spi_transaction_context_t
{
    spi_transaction_ext_t *trans_ext;
    void **rx_buf;
    size_t size;
    bool is_continuous_transactions;
    TickType_t timeout_ticks;
};

struct spi_master_cb_user_context_t
{
    struct {
        spi_master_user_cb_t user_cb;
        void *user_arg;
    } pre;
    struct {
        spi_master_user_cb_t user_cb;
        void *user_arg;
    } post;
};

void IRAM_ATTR spi_master_pre_cb(spi_transaction_t* trans)
{
    spi_master_cb_user_context_t *user_ctx = static_cast<spi_master_cb_user_context_t*>(trans->user);
    if (user_ctx->pre.user_cb) {
        user_ctx->pre.user_cb(trans, user_ctx->pre.user_arg);
    }
}

void IRAM_ATTR spi_master_post_cb(spi_transaction_t* trans)
{
    spi_master_cb_user_context_t *user_ctx = static_cast<spi_master_cb_user_context_t*>(trans->user);
    if (user_ctx->post.user_cb) {
        user_ctx->post.user_cb(trans, user_ctx->post.user_arg);
    }
}
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

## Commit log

2026-03-04 1st. commit
    [xiamocon.kicad_pcb, xiamocon.kicad_sch]
2026-03-13 PCB fixed
    [xiamocon.kicad_pcb, xiamocon.kicad_sch]
2026-03-16 pcb rev.2 part changed
    [xiamocon.kicad_pcb, xiamocon.kicad_sch]
2026-03-29 wip: ESP32-S3 support
2026-03-30 fix: schematic
    [xiamocon.kicad_sch]
2026-04-02 add simple enclosure
    [simple.step, simple.stl]
2026-04-03 fix enclosure
    [simple.step, simple.stl]
2026-04-06 fix sample app
2026-04-09 add filer sample
2026-04-12 add I2C bus reset and fix shutdown sequence
    [i2c.cpp, streaming_dac.cpp]
2026-04-12 support old ARM toolchain
2026-04-12 cancel support of old ARM toolchain
2026-04-20 add power off message
2026-04-26 fix SPI short DMA bug for ESP32S3
    [ESP32DMASPIMaster.h]
2026-04-27 fix audio noise for RP2350
    [streaming_dac.cpp]
2026-04-27 fix I2C library
2026-05-02 wip: enclosure
    [abxy_key.step, abxy_key.stl, back.step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]
2026-05-03 add full enclosure
    [abxy_key.step, back.step, dpad_key.step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]
2026-05-06 fix gfx2d_demo for ESP32S3
2026-05-06 add ADC API
2026-05-06 add PWM API
